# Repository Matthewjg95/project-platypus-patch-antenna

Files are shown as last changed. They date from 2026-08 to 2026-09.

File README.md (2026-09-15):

# Project Platypus — 2.4 GHz Microstrip Patch Antenna

A directional 2.4 GHz patch antenna on 2-layer FR4, designed from first principles —
no antenna generator, no reference design, no copied footprint. Every dimension is
derived from the cavity model and Hammerstad–Jensen microstrip synthesis, then
validated on manufactured hardware over a real RF link.

**Status: manufactured and functional. Gain vs the host's internal antenna is not
yet characterised.**

An early measurement produced an anomalously high delta and was excluded from
conclusions pending repeatability. Characterisation is in progress under a
controlled procedure — see [`TEST_PROCEDURE.md`](TEST_PROCEDURE.md) and
[`VNA_TEST_PLAN.md`](VNA_TEST_PLAN.md).

**Commercialization milestone:** On September 4, 2026, the Rev 2 development
project was **approved** for the Tindie × NextPCB Hardware Creator R&D Support
Program after applying on August 30. The award provides three monthly rounds of
standalone PCB-prototyping and international-shipping support. Rev 2 remains an
engineering-validation build: a sales listing is still gated on design review,
DFM, repeatable RF testing, and pilot-readiness evidence. Later support rounds
may be redirected to Platypus One carrier-board fabrication if the antenna
converges without another justified spin. See [`MILESTONES.md`](MILESTONES.md).

> Board photos: the panel is purple ENIG and photographs beautifully — see the Hackster
> project this repo accompanies.

---

## The board

One 58 × 210 mm V-scored panel, three antennas. Each board is 58 × 70 mm with an
M3 mounting pattern (44 mm square, matching the M5Tab5), a 50 Ω microstrip feed, and an
edge-launch MMCX jack (Cinch/Johnson 135-3711-801) seated in a routed notch.

### Why three designs on one panel

Impedance matching a patch has two textbook solutions. Rather than pick one on faith,
the panel carries **all three variants side by side** — same substrate, same fab run,
directly comparable:

| Design | Matching method | Geometry | Predicted Rin |
|---|---|---|---|
| **A** | Inset feed, calculated match | y₀ = 9.81 mm, slot 6.3 mm | 50 Ω (matched) |
| **B** | Inset feed, deliberate mismatch | y₀ = 7.50 mm, slot 6.3 mm | 97 Ω (control) |
| **C** | Quarter-wave transformer | Z_t = 100 Ω, w = 0.709 mm, ℓ = 17.98 mm | 50 Ω via λ/4 |

Design B is intentionally mismatched — the control that tests whether the matching
model is doing what the math claims.

---

## Design math (all first-principles)

Substrate: FR4, h = 1.6 mm, εr = 4.4, tan δ ≈ 0.02, 2 layers, ENIG.

```
Patch width      W = c/(2f₀)·√(2/(εr+1))                    = 38.04 mm
Effective εr     εr_eff = (εr+1)/2 + (εr−1)/2·(1+12h/W)^−½   = 4.086
Fringing ext.    ΔL = 0.412h·((εr_eff+0.3)(W/h+0.264)) /
                          ((εr_eff−0.258)(W/h+0.8))         = 0.742 mm
Patch length     L = c/(2f₀√εr_eff) − 2ΔL                    = 29.44 mm
50 Ω feed width  (Hammerstad–Jensen, FR4 1.6 mm)             = 3.1 mm
Inset depth      Rin(y₀) = Rin_edge·cos²(πy₀/L) → 50 Ω       = 9.81 mm
λ/4 transformer  Z_t = √(50·200) = 100 Ω, w = 0.709 mm, ℓ    = 17.98 mm
```

Resonance check: L_eff = 29.44 + 2(0.742) = 30.924 mm, √εr_eff = 2.021
→ **f₀ = 2.3996 GHz**.

**Inset slot width follows the Salmony method:** clearance each side of the feed must be
≥ the substrate height h, giving a 6.3 mm total slot (3.1 + 2×1.6). A slot barely wider
than the feed is a common mistake that creates spurious resonances and spoils the match.

### Honest analysis notes

- **Return loss is not signal loss.** A mismatch costs only 10·log₁₀(1−|Γ|²): even
  Design B's deliberate 97 Ω feed point loses well under 2 dB of delivered power. The
  A/B/C comparison therefore needs an S11 sweep (VNA), not RSSI — whatever advantage a
  patch shows over a chip antenna comes from directivity and escaping the host
  enclosure, not from matching finesse.
- **Front-to-back is modest by design.** The ground plane extends only 10–12 mm
  (≈0.1 λ) past the patch, so realistic F/B is ~6–10 dB. Fine for "point the gain at
  the far node"; don't expect a deep rear null indoors.

---

## Manufacturing notes (learned on real hardware)

- **ENIG is required** — HASL's uneven surface degrades RF pads.
- JLCPCB parses V-score geometry from **Edge.Cuts/GM1 only** — order notes and
  Dwgs.User lines are ignored. Their V-cut minimum panel size is 70 × 70 mm.
- The Edge.Cuts outline must be closed loops with exactly two segments per vertex; the
  MMCX notches are separate internal rectangles sharing no vertices with the perimeter.
- The MMCX signal pad sits inside the routed notch — contact is made by the connector's
  spring pin, and the corresponding DRC "unconnected" items are by design (waived in
  `patch_antenna_smp.kicad_dru` / DRC exclusions).
- Solder mask over the radiator shifts resonance down slightly (~10–30 MHz) but does
  not prevent operation.

## Repository layout

This repo now carries the **full project**, not just the manufactured revision — see
[`PROJECT_STATUS.md`](PROJECT_STATUS.md) for the live status, revision map, and
open decisions.

```
patch_antenna_smp.kicad_pcb      Rev 7.13.1 — the MANUFACTURED revision (do not edit)
gerbers/  +  gerbers.zip         Rev 7.13.1 fab package as manufactured (JLCPCB)
DRC7.13.1.rpt                    DRC report of the manufactured revision
patch_antenna_smp_rev8.*         Rev 8 — 3×3 panel respin (lessons-learned; superseded)
patch_antenna_smp_rev9.*         Rev 9 — dual SMT connector lands (u.FL + MMCX); current
rev9_fab/ + rev9_gerbers_jlcpcb.zip   Rev 9 JLCPCB fab+assembly package (BOM/CPL included)
rev8_backups/, rev9_backups/     Staged design snapshots (rollback points)
REV8_PLAN.md, REV9_CONNECTORS.md Revision change logs & design decisions
DESIGN_915_MESHTASTIC.md         915 MHz Meshtastic/LoRa patch — design study
DESIGN_NOTES_v72.md              Full first-principles derivation, BOM, fab notes
TEST_PROCEDURE.md                Over-the-air RF test protocol
VNA_TEST_PLAN.md                 Bench characterisation milestones (S11, gain, pattern)
PROJECT_STATUS.md                Current state, toolchain notes, transfer guide
BOM/Links.txt                    Component sourcing
```

## Bill of materials (per board)

| Ref | Part | Notes |
|---|---|---|
| J1 | MMCX 135-3711-801 (Cinch/Johnson) | Edge-launch jack, board notch |
| H1–H4 | M3 × 6 mm screw + 5 mm nylon standoff | Nylon preferred for RF isolation |
| — | Pigtail: SMP-male → MMCX-male, RG178, ~100 mm | Host-device dependent |

**Fab settings:** 2-layer FR4 1.6 mm, ENIG, purple mask, white silk,
V-score at 70 mm and 140 mm from panel top.

## License

Hardware and documentation are released under the
**[CERN Open Hardware Licence v2 — Strongly Reciprocal](LICENSE)** (CERN-OHL-S v2).
You may use, study, modify, manufacture and sell this design, provided derivative
hardware designs are shared under the same terms.

---

*Project Platypus — Open Source RF*

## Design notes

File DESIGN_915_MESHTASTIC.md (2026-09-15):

# Project Platypus — 915 MHz Meshtastic/LoRa Patch (design study)

*Started 2026-07-05. First-principles design, same method as the proven 2.4 GHz panel.*

## Target

Directional gain antenna for Meshtastic / LoRa point-to-point links, US 902–928 MHz band.
Design frequency: **906.875 MHz** (Meshtastic US LongFast default primary), not 915 —
the patch is narrowband, so tune to where the traffic actually is. An EU868 variant
(869.525 MHz) is a later length-scale respin.

## First-principles dimensions (FR4, h = 1.6 mm, εr = 4.4, tan δ = 0.02)

```
f0 = 906.875 MHz            λ0 = 330.7 mm
Patch width W    = 100.66 mm
εr_eff           = 4.258
ΔL (fringing)    = 0.745 mm
Patch length L   = 78.67 mm
50 Ω feed width  = 3.06 mm   (Hammerstad-Jensen; same as 2.4 GHz design)
100 Ω xfmr width = 0.709 mm ; λg/4 = 47.6 mm  (transformer variant — long, see below)
Inset (200 Ω edge assumption):  y0 = 26.22 mm
Inset (Balanis edge ~376 Ω):    y0 = 29.99 mm
Bandwidth (VSWR<2): ~0.41 % ≈ 3.7 MHz
```

**Feed choice: inset feed.** The λ/4 transformer costs 47.6 mm of board height at this
frequency; the inset is free. (The 2.4 GHz A-vs-C test showed matching method makes <1 dB
difference — pick the compact one.)

## THE design risk at 915: FR4 εr tolerance vs. 3.7 MHz bandwidth

f0 sensitivity at fixed geometry (designed for εr = 4.4):

| FR4 εr actual | f0 lands at | shift |
|---|---|---|
| 4.2 | 927.9 MHz | +21 MHz |
| 4.4 | 906.9 MHz | 0 |
| 4.6 | 887.2 MHz | −20 MHz |

A ±0.2 εr batch spread moves resonance **±20 MHz against a 3.7 MHz bandwidth** — a 5×
overshoot. At 2.4 GHz we got away with this (BW ~25 MHz, same fractional shift); at 915
we will not. Mitigation, in the proven Project Platypus style — **bracket panel**:

| Variant | L | f0 if εr=4.4 | covers εr ≈ |
|---|---|---|---|
| A (short) | 77.09 mm (−2%) | 925.0 MHz | ~4.2 |
| B (nominal) | 78.67 mm | 906.9 MHz | ~4.4 |
| C (long) | 80.24 mm (+2%) | 889.4 MHz | ~4.6 |

One panel run tells us the batch's real εr; the winning variant becomes the product
geometry for that fab. Selection can be done with Meshtastic's own RSSI/SNR reports
between two nodes; a NanoVNA (on the roadmap) makes it a 5-minute S11 sweep instead.

## Board / panel

- Patch 100.7 × 78.7 mm → board ~**130 × 115 mm** (12–15 mm ground margin + feed run).
  Margins are only ~0.04 λ — front-to-back will be modest (~6–10 dB), same physics as
  the 2.4 GHz board. Fine for "point the gain at the far node"; don't market F/B.
- 3 variants stack into a 1×3 V-scored panel ~130 × 345 mm, or 2×3 (~260 × 345) for
  bracket + spare. Both exceed JLCPCB's 70 mm V-cut minimum in both axes. V-cuts on
  Edge.Cuts (GM1), keep-all-islands ground — all per the Rev 8 playbook.
- Solder mask: **openings over the patch** (bare ENIG radiator) — carry the Rev 8 fix.
  At 0.4 % bandwidth we cannot afford unmodelled mask detune.
- Mounting: keep the M3 hole pattern idea, sized for a mast clamp / zip ties instead of
  the M5Tab5 pattern.

## Connector (product-driven, differs from the Tab5 board)

- **On-board: u.FL/IPEX jack** (vertical SMT, ~$0.40). It is the de facto standard on
  Heltec/RAK/LILYGO Meshtastic nodes, needs no routed notch, no edge-launch DRC waivers,
  no spring-pin ambiguity — the feed simply ends in a pad, grounds via to the plane.
- **Ship with a u.FL → SMA-male pigtail** so it also screws straight onto boxed nodes
  (SMA female bulkhead), covering both halves of the market with one SKU.
- Optional second footprint position for a vertical SMT MMCX jack (e.g. Cinch
  135-3701-201) sharing the feed end — populate either. Decide after the 2.4 GHz
  connector experiments.

## Roadmap / open items

1. Freeze bracket-panel geometry; build the KiCad board (new project dir, not in the
   2.4 GHz tree).
2. **NanoVNA** purchase → measure S11 of 2.4 GHz Rev 7.13 A/B/C first (validates the
   whole design chain and the 200 Ω edge-resistance assumption), then use for 915
   variant selection.
3. EU868 respin (scale L for 869.525 MHz) once US geometry is proven.
4. Field range test: two Meshtastic nodes, omni-vs-patch A/B, logged SNR vs distance —
   that's also the marketing material.

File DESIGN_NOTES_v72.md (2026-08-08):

# Project Platypus — 2.4 GHz Patch Antenna
## Design Notes Rev 7.2 — Release for Manufacture

---

## Project Overview

A panelised 2.4 GHz microstrip patch antenna PCB designed for external antenna integration with the M5Tab5. Three distinct impedance-matching designs are included on a single V-scored panel for comparative RF testing. The winning design will be used in Rev 8 production boards. Performance is quantified using the M5Tab5's own WiFi RSSI and the BMI270 gyroscope to render a live 3D radiation pattern on the display.

---

## Board Summary

| Parameter | Value |
|---|---|
| Target frequency | 2.4 GHz (802.11b/g/n, Bluetooth, Zigbee) |
| Panel size | 58 × 210 mm (3 boards × 70 mm each) |
| Individual board | 58 × 70 mm |
| Substrate | FR4, h = 1.6 mm, εr = 4.4, tan δ = 0.02 |
| Copper layers | 2 (F.Cu patch + feed, B.Cu full ground plane) |
| Surface finish | ENIG |
| Solder mask | **Purple** |
| Silkscreen | **White** (both sides) |
| Panelisation | V-score between boards (2 score lines) |
| Mounting | M3 NPTPH, 44 mm square pattern (matches M5Tab5) |
| Connector | MMCX 135-3711-801 end-launch jack, board notch |

---

## Patch Antenna Calculations

All dimensions derived from first principles for 2.4 GHz on FR4 1.6 mm.

### Patch Width

```
W = c / (2f₀) × √(2 / (εr + 1))
W = 3×10⁸ / (2 × 2.4×10⁹) × √(2 / 5.4)
W = 38.04 mm
```

### Effective Dielectric Constant

```
εr_eff = (εr+1)/2 + (εr-1)/2 × (1 + 12h/W)^(-0.5)
εr_eff = 4.086
```

### Patch Length

```
ΔL = 0.412h × (εr_eff+0.3)(W/h+0.264) / ((εr_eff-0.258)(W/h+0.8))
ΔL = 0.742 mm

L_eff = c / (2f₀√εr_eff) = 30.93 mm
L = L_eff - 2ΔL = 29.44 mm
```

### 50 Ω Microstrip Feedline

```
Feed width W_feed = 3.1 mm  (Hammerstad-Jensen, FR4 1.6 mm)
εr_eff_feed ≈ 3.38
```

### Inset Slot Width (Salmony method)

Slot clearance on each side of the feedline must be ≥ substrate height h to prevent capacitive coupling into the patch copper:

```
Slot clearance = h = 1.6 mm each side
Total slot width = W_feed + 2h = 3.1 + 3.2 = 6.3 mm
```

This corrects the common mistake of using a slot barely wider than the feedline, which creates spurious resonances and degrades the impedance match.

---

## Three Designs

### Design A — Inset Feed, Calculated Match (Reference)

The inset feed exploits the cosine-squared current distribution of the patch. Input impedance varies from ~200 Ω at the radiating edge to 0 Ω at the patch centre. The inset depth y₀ selects the exact point where impedance equals 50 Ω.

```
Rin(y₀) = Rin_edge × cos²(π y₀ / L)
50 = 200 × cos²(π y₀ / 29.44)
y₀ = 9.81 mm
Rin at y₀ = 50.0 Ω  ✓ matched
Slot: 6.3 mm wide × 9.81 mm deep
```

**This is the primary design.** Expected best broadside gain.

### Design B — Inset Feed, Deliberate Mismatch (Experiment)

Identical geometry to Design A but with a shallower inset. The feed point is higher up the patch where impedance is ~97 Ω rather than 50 Ω. This controlled mismatch tests the sensitivity of the antenna to inset depth error and provides data to validate the matching formula experimentally.

```
y₀ = 7.50 mm  (shallower than calculated optimum)
Rin at y₀ = 97.0 Ω  → mismatch Γ = (97-50)/(97+50) = 0.32
Expected return loss ≈ 9.8 dB  (vs >20 dB for Design A)
```

**Expected measurably worse RSSI than Design A.** If the delta is not observed, it suggests the 50 Ω assumption for the feedline is the dominant error, not the inset depth.

### Design C — Quarter-Wave Transformer (Alternative Matching)

No inset notch. The 50 Ω feedline transitions to a higher-impedance transformer section before connecting to the centre of the patch's radiating bottom edge. The transformer impedance Z_t and length λ_g/4 perform the same 200 Ω → 50 Ω transformation as the inset, but via an external line section rather than feed positioning.

```
Z_t = √(Z₀ × Rin) = √(50 × 200) = 100 Ω
Transformer width W_t = 0.709 mm  (100 Ω microstrip, FR4 1.6 mm)
εr_eff_t = 3.118
λ_g/4 at 2.4 GHz = c / (4 × f₀ × √εr_eff_t) = 17.98 mm
```

The patch is a plain rectangle with no notch slots. The feed enters at the bottom-centre radiating edge. The step from 3.1 mm (50 Ω) to 0.709 mm (100 Ω) is an abrupt width change — the standard Salmony method. Bandwidth of this match is similar to the inset approach.

**Useful for comparison:** if Design C outperforms Design A it suggests the inset slots are introducing parasitic coupling despite the 1.6 mm clearance.

---

## Connector — MMCX 135-3711-801

End-launch jack receptacle, surface mount, Bel/Cinch group. Selected for compatibility with the M5Tab5's MMCX external antenna ports.

| Pad | Net | Size | Position (rel. to footprint origin) |
|-----|-----|---|---|
| 1 (signal) | RF_IN | Ø 0.71 mm | (0, +3.30 mm) — inside notch |
| 2 (GND left) | GND | 0.97 × 1.47 mm | (−2.235, −0.735 mm) |
| 3 (GND right) | GND | 0.97 × 1.47 mm | (+2.235, −0.735 mm) |

**Board notch:** 3.50 mm wide × 4.50 mm deep, rectangular, routed into the board bottom edge. The signal pad sits 3.30 mm below the board edge inside the routed slot. The feedline copper terminates exactly at the board edge — it does not extend into the notch.

**Pigtail cable:** SMP male to MMCX male, RG178, ~100 mm. Plugs into M5Tab5 MMCX port and snaps into J1 on this PCB.

---

## Panel & Fabrication

### V-Score Panelisation

The three boards share a single continuous `Edge.Cuts` outline (one panel). V-score lines run the full panel width at y = 113.5 mm and y = 183.5 mm in panel coordinates (= 70 mm and 140 mm from the panel top edge). JLCPCB will route the MMCX notch slots first, then apply the V-score blade.

**JLCPCB order note to include:**
> "V-score at 70 mm and 140 mm from panel top edge (panel y = 113.5 mm and y = 183.5 mm). Three MMCX slots (3.50 × 4.50 mm) pre-routed at each board bottom edge. No solder mask on F.Cu patch copper areas. Purple solder mask, white silkscreen, ENIG finish."

### Critical Fabrication Requirements

- **No solder mask on patch copper** — solder mask over the radiating element changes εr_eff and shifts the resonant frequency. Specify a solder mask opening over the patch polygon on each board (the Gerbers include this as a B.Mask opening).
- **ENIG finish** — required for RF performance. HASL creates uneven surface topology under the connector pads and patch copper.
- **Purple solder mask** — select in JLCPCB order form. No extra cost for 2-layer boards. Turnaround +2 days vs green.
- **White silkscreen** — default for purple mask, no action needed.

### Mounting

M3 NPTPH holes (3.2 mm drill, no plating) in a 44 mm square pattern, 7 mm from each board side, 5 mm from board top. This matches the M5Tab5's M3 mounting point positions exactly. Use M3 socket-head cap screws with nylon spacers to mount the antenna PCB above the M5Tab5 body with the patch face pointing away from the device.

---

## Bill of Materials

| Ref | Part | Qty (per board) | Notes |
|-----|---|---|---|
| J1 | MMCX 135-3711-801 (Bel/Cinch) | 1 | DigiKey, Mouser |
| H1–H4 | M3 × 6 mm socket head cap screw | 4 | Nylon preferred for RF isolation |
| H1–H4 | M3 nylon standoff, 5 mm | 4 | Between this PCB and M5Tab5 |
| — | SMP male to MMCX male pigtail, RG178, 100 mm | 1 | Pasternack, Amazon |
| PCB | This file, JLCPCB 2-layer | 1 panel (3 boards) | Purple, ENIG |

**Note:** Order 2 panels (10 boards) for testing redundancy. At JLCPCB pricing this is approximately $8–12 shipped.

---

## Key Design Decisions & Revision History

| Rev | Change |
|-----|---|
| 1.0 | Initial inset-feed patch, SMP edge connector |
| 2.0 | Updated to MMCX 135-3711-801, M3 holes, 44 mm pattern |
| 3.0 | Three-design panel (A/B/C), V-score panelisation |
| 4.0 | Patch moved inside mounting hole square, board notch corrected to rectangular |
| 5.0 | Single panel Edge.Cuts outline (boards actually connected), patch U-polygon with visible notch slots |
| 5.1 | Feed copper capped at board edge (was extending 3.3 mm past edge into routed notch — fabrication error) |
| 6.0 | Panel properly connected, V-score lines on Dwgs.User |
| 7.0 | Slot width corrected from 4.1 mm to 6.3 mm per Salmony method (h clearance each side). Purple solder mask specified. Project Platypus branding. |
| 7.1 | Logo moved to B.SilkS back silkscreen, notes box placed outside board boundary |
| 7.2 | Logo replaced with "Project Platypus" text in lower-right corner. Notes box corrected. |
| 7.3–7.13 | DRC iteration: zone priorities fixed, GND zone unified, vias removed (no F.Cu GND to stitch to), connector GND zones with vias added, MMCX edge clearances waived, Edge.Cuts rebuilt as outer perimeter + 2 internal notch rectangles (no T-junctions), V-score positions verified at y=113.5 and y=183.5. **Release for manufacture.** |

---

## Expected Performance

| Metric | Design A | Design B | Design C |
|---|---|---|---|
| Resonant frequency | 2.40 GHz | 2.40 GHz | 2.40 GHz |
| Return loss (S11) | > 20 dB | ~10 dB | > 15 dB |
| Bandwidth (−10 dB) | ~80 MHz | ~30 MHz | ~70 MHz |
| Gain (broadside) | 5–7 dBi | 3–5 dBi | 4–6 dBi |
| RSSI delta vs stock | +4 to +7 dBm | +1 to +3 dBm | +3 to +5 dBm |

All values are estimates based on standard FR4 patch theory. Actual performance will be measured per the TEST_PROCEDURE.md protocol.

---

## Next Steps After Receipt

1. **Visual inspection** — confirm purple mask, white silk, ENIG finish, MMCX notch clean
2. **VNA measurement** — if available, measure S11 on each board before RF testing. Resonance within ±50 MHz of 2.4 GHz is acceptable without rework
3. **Connector installation** — solder J1 (MMCX 135-3711-801) with paste and reflow or careful iron work. Pads are small — use flux
4. **RF switch** — confirm M5Tab5 GPIO for antenna switching (external vs chip antenna). Check Tab5 schematic for GPIO number controlling the RF switch on the ESP32-C6-MINI-1U
5. **Follow TEST_PROCEDURE.md** — baseline first, then each design in order A → B → C
6. **3D pattern capture** — run the full hemisphere sweep on the winning design, process with the Python pipeline, render on M5Tab5 display via Three.js + BMI270 gyro

---

*Project Platypus — Open Source RF*
*Rev 7.2 — Ready to manufacture*

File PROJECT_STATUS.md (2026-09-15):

# Project Platypus — Status & Transfer Guide

*Last updated 2026-09-14. This file exists so the whole project moves between machines
with one `git clone` and no tribal knowledge. Everything below is in this repo.*

## What this project is

First-principles 2.4 GHz microstrip patch antennas (KiCad, FR4 1.6 mm), plus a product
track (Tindie) and a 915 MHz Meshtastic design study. Full derivations in
`DESIGN_NOTES_v72.md` and the README.

**Measurement status:** the boards are manufactured and functional. An early RSSI
delta vs the host chip antenna was anomalously high and has been withdrawn pending a
controlled re-test — do not cite it. Bench characterisation plan: `VNA_TEST_PLAN.md`.

## Revision map

| Revision | File(s) | State |
|---|---|---|
| **Rev 7.13.1** | `patch_antenna_smp.kicad_pcb` (+`.kicad_pro`, `.kicad_dru`), `gerbers/`, `gerbers.zip`, `DRC7.13.1.rpt` | **Manufactured.** 1×3 panel, edge-launch MMCX. Never edit in place. |
| **Rev 8** | `patch_antenna_smp_rev8.*`, `REV8_PLAN.md`, snapshots in `rev8_backups/` | Complete + DRC-verified. 3×3 panel 174×210 mm, V-cuts on Edge.Cuts, keep-all-islands ground, bigger MMCX pads, mask experiment (left column bare / two masked). Superseded by Rev 9 for ordering. |
| **Rev 9** | `patch_antenna_smp_rev9.*`, `REV9_CONNECTORS.md`, snapshots in `rev9_backups/`, fab package `rev9_fab/` + `rev9_gerbers_jlcpcb.zip` | Complete + DRC-verified. Dual SMT lands per board: Hirose U.FL (JUA–JUI) + Würth vertical MMCX (JMA–JMI), no notches. **This is the revision to order.** |
| **915 MHz** | `DESIGN_915_MESHTASTIC.md` | Design study done, KiCad board not started. Key: 3-length bracket panel (FR4 εr tolerance vs 3.7 MHz bandwidth). |

## Pending / open decisions

1. **Rev 9 fabrication order** — package is upload-ready. Funding (see
   `MILESTONES.md`): the Tindie × NextPCB vouchers ($30/mo ×3 + shipping) cover
   **standalone PCB fabrication at NextPCB only — not PCBA**; the separate $20
   JLCPCB credit can offset a JLCPCB assembly order. Options: (a) NextPCB
   bare-panel run on the voucher + hand-solder connectors, or (b) JLCPCB PCBA —
   u.FL from their library (Hirose **C88373**), Würth MMCX via Global Sourcing
   (~$4–5/pc, +1 wk) or hand-soldered. Population map in `rev9_fab/BOM_rev9.csv`
   / `CPL_rev9.csv` (MMCX cols 1&3, u.FL col 2). If using JLC assembly, check
   connector rotations in their preview (u.FLs are at −90°). Per MILESTONES.md,
   any new spin beyond this must be justified by measurement, not coupon availability.
2. **VNA milestones** (`VNA_TEST_PLAN.md`): buy a NanoVNA-V2 Plus4 / LiteVNA-64 (NOT
   the original NanoVNA); M1–M2 on the Rev 7.13 boards settle the patch-A connector
   question and the Rin_edge assumption. M5 (gain/pattern) uses the work radar bench —
   this produces the number that replaces the withdrawn claim.
3. **915 bracket panel**: start KiCad board after the Rev 9 order is in flight.

## Toolchain & workflow (as used to build Rev 8/9)

- **KiCad 10.0.1.** GUI plus headless: `kicad-cli` and the bundled Python
  (`C:\Program Files\KiCad\10.0\bin\python.exe`, module `pcbnew`) for scripted edits.
- **Validation is a DRC delta-check**: `kicad-cli pcb drc` does NOT apply GUI
  exclusions, so compare violation *categories* against the documented expected set
  (see `REV9_CONNECTORS.md` § verified DRC state), not against zero. It DOES honor
  `.kicad_dru` custom rules.
- Always **Fill All Zones (B) in the GUI before export** after any zone edit.
- pcbnew scripting gotchas (hard-won): `LoadBoard` twice in one process returns a raw
  SwigPyObject — run phases as separate processes; removing tracks in a loop can
  segfault — prefer add-only edits; `Duplicate()` needs `.Cast()` and loses nothing
  but check nets anyway.
- Windows: ignore SWIG "memory leak" stderr noise from pcbnew scripts.

## Moving to a new machine

```
git clone https://github.com/Matthewjg95/project-platypus-patch-antenna.git
```

Then: install KiCad ≥10, `gh auth login`, set git identity, and open
`patch_antenna_smp_rev9.kicad_pcb`. The `rev8_backups/`/`rev9_backups/` folders are
staged design snapshots (rollback points); git history is authoritative. Not in the
repo (by design): `.history/` editor cache, `*.kicad_prl` window state, vendor
datasheet PDFs (links in `BOM/Links.txt`).

## Product / licensing

CERN-OHL-S v2 (`LICENSE`). Commercial sale is permitted by the license, and as sole
copyright holder you may also dual-license. Tindie plan: bare / assembled / kit SKUs;
market via Meshtastic + ELRS communities once characterisation data exists.

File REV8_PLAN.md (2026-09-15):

# Project Platypus — Rev 8 Plan

## Status
Rev 7.13.1 is manufactured, assembled, and functional; gain vs the M5Tab5 chip antenna
is not yet characterised. Rev 8 folds in every lesson learned from that build. This file
is the durable change list and the record of design decisions made while implementing it.

The known-good manufactured file (`patch_antenna_smp.kicad_pcb`, the 1×3 panel) is **not**
edited in place. Rev 8 work happens on a copy so the shipped design is always recoverable.

---

## Implementation status — 2026-07-05

Rev 8 is built on the working copy `patch_antenna_smp_rev8.kicad_pcb` (staged snapshots in
`rev8_backups/`). Validated with `kicad-cli 10.0.1` (delta check — it does not apply the
GUI `.kicad_dru` waivers or exclusions, so by-design items always appear).

**Done and verified:**
- MMCX GND pads enlarged to 1.5×2.0 mm; feed tapered 3.1→1.0 mm; 2.0×2.0 signal-pad mask
  aperture + patch F.Mask openings. DRC delta clean (no new categories) on the 1×3.
  (snapshots `rev8_02`)
- 3×3 panel 174.1×210.1 mm: 9 boards (JA–JI + 36 M3), 40 zones, 18 vias. Outer perimeter
  + 3 bottom C-notches + 6 internal A/B notches rebuilt clean. GND_PANEL extended to full
  panel and set to **keep-all islands** so every board keeps its own ground (inset 0.5 mm
  from score lines) — fill 34,909 mm² across all 9 boards. V-cut lines added on Edge.Cuts
  between all rows (y=113.5, 183.5) and columns (x=239, 297). (snapshots `rev8_04`, `rev8_05`)
- Broadened `.kicad_dru` edge-clearance waiver to all F.Cu GND pads (covers JA–JI).
- Title/rev strings updated to Rev 8.

**Final panel DRC (all expected / waived / by-design — no real defects):**
- `copper_edge_clearance` ×18 — MMCX GND pads on notch walls (waived by `.kicad_dru`).
- `unconnected_items` ×16 — 10 RF_IN (spring-pin contact, by design) + 6 GND (see below).
- `isolated_copper` ×32 — 23 RF_IN patch radiators (by design; reached only via connector
  pin) + 9 GND edge slivers.
- `invalid_outline` ×8 — the four V-cut lines touching the perimeter (the Edge.Cuts V-cut
  tradeoff; exclude).
- `silk_over_copper` ×6 — Design B/C labels (cosmetic; same as Rev 7.13).

**Known non-issue — 6 GND `unconnected_items`:** the left-side connector grounds in columns
1–2 (`CONN_GND_*_L_C1/C2`) show a ratsnest line to GND_PANEL. Proven a headless-fill
connectivity artifact: each via is geometrically inside both its F.Cu CONN_GND fill and the
B.Cu ground plane, on the same net (netcode 2), identical to the working column-0 / right-side
connections. It is functionally harmless regardless — the MMCX body shorts pads 2 & 3, and the
right-side via grounds every connector. Should resolve on GUI Fill All Zones. Do NOT "fix" by
adding in-pad vias near the notch (they violate edge clearance).

**Open decision — V-cuts on Edge.Cuts vs. continuous ground:** current design puts V-cuts on
Edge.Cuts (per the JLCPCB lesson that Dwgs.User is ignored). Cost: 8 `invalid_outline`
warnings + the ground fragmenting into per-board tiles (handled with keep-all). Alternative:
keep V-cuts off Edge.Cuts for a continuous plane + clean DRC, and communicate V-cut positions
to JLCPCB another way. Left as-is pending user preference.

## RF design parameters (locked — unchanged from Rev 7)
```
Frequency        2.4 GHz            Patch width W     38.04 mm
Substrate        FR4 1.6 mm         Patch length L    29.44 mm
εr 4.4, tanδ 0.02  εr_eff 4.086     ΔL (fringing)     0.742 mm
50 Ω feed width  3.1 mm             Rin at edge       ~200 Ω
Design A inset   y0 = 9.81 mm → 50 Ω (matched)
Design B inset   y0 = 7.50 mm → 97 Ω (deliberate mismatch)
Design C xfmr    Zt = 100 Ω, w = 0.709 mm, L = 17.98 mm (no inset)
```
No RF geometry changes in Rev 8 — the electrical design is validated. Rev 8 is purely
manufacturability + panelisation improvements.

---

## Change list

### 1. MMCX 135-3711-801 footprint — manufacturability fixes
Problems seen on Rev 7.13:
- **Feed crowding.** 3.1 mm feed in a 3.50 mm notch = 0.2 mm clearance per side; the
  connector GND legs nearly shorted to the signal feed. (Rev 7.13 workaround: solder
  mask over the feed insulated the legs.)
- **No usable mask opening on the signal pad.** Had to scrape mask by hand before
  soldering. (The pad *had* F.Mask in its layer list, but the 0.71 mm opening was too
  small/tight to be useful.)
- **GND pads too small** for Class 3 workmanship (0.97 × 1.47 mm).

Rev 8 fixes (geometry decided during implementation — see "Decisions" below):
- ~~Taper the feed from 3.1 mm to 1.0 mm.~~ **REVERTED 2026-07-05.** The routed connector
  notch (the "hole") already separates the feed from the GND legs — the feed fill is clipped
  at the notch edge and the spring pin bridges to the signal pad, so there is no real feed-to-
  GND crowding. Tapering just removed copper and added a needless impedance discontinuity.
  Feed is back to straight 3.1 mm microstrip (the proven Rev 7.13 geometry).
- **Signal-pad mask aperture 2.0 × 2.0 mm**, added as a mask-only pad centred on the
  signal pad, so the whole pin-contact area is bare ENIG.
- **GND pads enlarged to 1.5 × 2.0 mm.** Grown *outward in x* (inner edge kept exactly
  on the notch wall) and *upward in y* (bottom edge kept flush with the board edge).
  The connector's ground leg still lands well inside the enlarged pad.

### 2. Solder mask off the radiator — bare-vs-masked A/B test
Rev 7.13 shipped with **no** F.Mask openings over the patch copper (mask covered the
patches). It worked but detuned resonance ~10–30 MHz downward. Rev 8 makes patch masking a
deliberate experimental variable: **the LEFT column (all 3 designs A/B/C) is bare copper**
(F.Mask opening over the patch), and the **middle + right columns are masked**. That gives a
bare-vs-masked pair for every design so the mask detuning can be measured per design without
confounding it with the design difference. The bare patches read gold/ENIG, the masked ones
purple — self-identifying, no silk label needed (a note is added to the User.Drawings legend).
The **feed stays masked** everywhere on purpose — mask over a transmission line is negligible
and it insulates the connector GND legs from the feed. Only the left-column radiators go bare.
(Earlier interim state had all 9 patches bare; narrowed to one column on user request.)

### 3. Panelisation — 3×3, V-cuts on Edge.Cuts
Rev 7.13 was a 58 × 210 mm 1×3 panel. Two problems at JLCPCB:
- **Below V-cut minimum.** JLCPCB's V-cut minimum panel size is 70 × 70 mm; our 58 mm
  width was under it, so they could not V-score horizontally between designs.
- **V-scores on Dwgs.User were ignored.** JLCPCB parses geometry on Edge.Cuts / GM1,
  not Dwgs.User. Order notes are not a substitute.
- JLCPCB "helpfully" multiplied our panel into a 3×3 array (174 × 210 mm) anyway.

Rev 8 plan: design the full **3×3 panel = 174 × 210 mm** up front (both dimensions
> 70 mm), 3 columns × 3 rows = 9 boards, one design per row (A / B / C), three copies of
each across the columns. V-cut lines go on **Edge.Cuts** between every row and column.

> **Open technical caveat (V-scores on Edge.Cuts):** a V-score line that spans the full
> panel width and touches the perimeter creates T-junctions, which KiCad reports as
> `invalid_outline`. The clean board shape (outer perimeter + separate internal MMCX
> notch rectangles, no shared vertices) is what keeps DRC quiet. Putting full-span
> V-cut lines back on Edge.Cuts re-introduces those warnings. The resolution is to keep
> the true outline clean and add the V-cut lines as independent Edge.Cuts segments,
> accepting/【excluding】the resulting outline warnings — that is the tradeoff for JLCPCB
> reading them from GM1. This is validated with `kicad-cli pcb drc` during implementation.

### 4. Consider soldermask-defined openings for all connector pads
Evaluate SMD-defined vs mask-defined for the GND and signal pads. Low priority; only if
the enlarged pads still show mask slivers in the fab preview.

---

## Decisions made during implementation

### MMCX footprint geometry (origin = connector centre, at the board edge; +y = toward/past the edge)
| Element | Rev 7.13 | Rev 8 | Rationale |
|---|---|---|---|
| Signal pad (1) | Ø 0.71 @ (0, +3.30) | unchanged copper | pin contact point is fixed |
| Signal mask | 0.71 (= pad) | **2.0 × 2.0 aperture @ (0, +3.30)** | bare area for hand/reflow solder |
| GND pad L (2) | 0.97 × 1.47 @ (−2.235, −0.735) | **1.5 × 2.0 @ (−2.5, −1.0)** | bigger, inner edge on notch wall, bottom flush to edge |
| GND pad R (3) | 0.97 × 1.47 @ (+2.235, −0.735) | **1.5 × 2.0 @ (+2.5, −1.0)** | mirror of pad 2 |

Notch wall at rel x = ±1.75 (abs 208.25 / 211.75). Enlarged GND pad inner edge = 2.5 −
0.75 = 1.75 → sits exactly on the notch wall (same as Rev 7.13's 2.235 − 0.485 = 1.75),
covered by the existing `edge_clearance (min 0mm)` DRC rule. Bottom edge at rel y = 0 =
board edge (V-score line); grows upward into the board to rel y = −2.0.

### Feed geometry — straight 3.1 mm (taper reverted)
Feed zones are plain 3.1 mm rectangles x [208.45+dx, 211.55+dx] from the patch bottom to the
board edge (dx = 0 / 58 / 116 per column). The fill is clipped by the routed MMCX notch, and
the connector spring pin bridges to the signal pad — no copper crowding, no taper needed.
- Design A feed: y 85.2212 → 113.5
- Design B feed: y 155.2212 → 183.5
- Design C feed: y 243.201 → 253.5 (plus the unchanged XFORM_C 0.709 mm transformer)

### Patch mask openings
Filled polygon on F.Mask over each patch bounding box (radiator only, not feed):
- A: (190.982, 55.779)–(229.018, 85.221)
- B: (190.982, 125.779)–(229.018, 155.221)
- C: (190.982, 195.779)–(229.018, 225.221)

---

## Zone priority hierarchy (unchanged — prevents zones_intersect)
```
PATCH_A/B/C   priority 3   XFORM_C      priority 2
FEED_A/B/C    priority 1   GND_PANEL    priority 0   CONN_GND_*  priority 0
```
- ONE B.Cu GND_PANEL zone covering the whole panel (spans all 3 columns in Rev 8).
- CONN_GND zones: solid fill, `connect_pads yes (clearance 0)`, one via each to GND_PANEL.
- No stitching vias — all F.Cu copper is RF_IN, nothing to stitch.

## Build / verify workflow
1. Edit the Rev 8 copy.
2. **Fill All Zones (press B)** in KiCad — filled_polygon data in the file is stale after
   any zone-outline edit until refilled. `kicad-cli pcb drc` refills before checking.
3. `kicad-cli pcb drc --schematic-parity ... ` — expect only the waived items:
   - `unconnected_items` on RF_IN signal pads (spring-pin contact) — exclude.
   - MMCX GND edge clearance — waived by `.kicad_dru`.
   - Edge.Cuts outline warnings from V-cut lines — exclude (see caveat above).
4. Re-export gerbers to `gerbers/` and re-zip for JLCPCB.

## Fab order (JLCPCB)
Purple mask, white silk, ENIG, FR4 1.6 mm, 2-layer. 3×3 panel 174 × 210 mm. V-cut on
GM1 between all rows and columns. No mask on patch copper. MMCX slots 3.5 × 4.5 mm routed.

## KiCad S-expr pitfalls (carried forward)
- `(justify center)` invalid in older formats — omit (centre is default).
- `fill solid` invalid — use `fill yes`.
- `;;` comments break the parser.
- `gr_rect` cannot carry a net — use `zone` for copper pours.
- Edge.Cuts outline must be closed loops, exactly 2 segments per vertex, no T-junctions.
- Same-net zones touching on the same layer need different priorities.

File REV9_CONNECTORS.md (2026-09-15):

# Rev 9 — Dual SMT Connector Respin (u.FL + vertical MMCX)

*Created 2026-07-21. Working file: `patch_antenna_smp_rev9.kicad_pcb` (branched from Rev 8
snapshot `rev8_08`; Rev 8 remains the frozen fab-ready edge-launch panel). Snapshots in
`rev9_backups/`.*

## Concept

Every board carries **both** connector lands on the feed axis — populate either one:

- **u.FL / IPEX MHF1** (Hirose U.FL-R-SMT-1) — the de facto standard on Meshtastic/LoRa/
  ESP32 dev boards. Vertical mate, cable exits perpendicular to the board face.
- **Vertical SMT MMCX** (Würth WR-MMCX 66012102111404) — locking snap connector, mates the
  existing SMP-to-MMCX pigtail vertically. Fixes the edge-launch "double 90°" cable exit.

Both are placed using the **official KiCad 10 footprints** (datasheet-derived):
`Connector_Coaxial.pretty/U.FL_Hirose_U.FL-R-SMT-1_Vertical` and
`WR-MMCX_Wuerth_66012102111404_Vertical`.

## Default BOM (low-cost)

| Role | Default part | ~Cost (qty 1/100) | Notes |
|---|---|---|---|
| u.FL jack | Hirose U.FL-R-SMT-1(10) | $0.55 / $0.35 | LCSC clones (I-PEX MHF1 compatible, e.g. BWIPX-1-001E) ~$0.10 — same land pattern |
| SMT MMCX jack | Würth 66012102111404 | $3.40 / $2.60 | KiCad-official land. Cheaper LCSC MMCX SMT verticals exist but MUST be pattern-checked against this land before substituting |
| Pigtail (u.FL SKU) | u.FL → SMA-male, RG178, 100–200 mm | $3–5 | covers boxed-node users |
| Pigtail (Tab5 kit) | SMP-male → MMCX-male (existing) | — | mates the vertical MMCX directly |

## Per-board geometry (board coords: cx = column centre, ye = board bottom edge)

```
Feed:        3.1 mm (50 Ω) from patch bottom to ye−9.5
Neck:        0.6 mm wide from ye−9.5 to ye−3.5 (through MMCX wing channel, onto u.FL pad)
MMCX (JM_)   centre at (cx, ye−7), pad1 Ø1.47 on the neck
u.FL (JU_)   centre at (cx, ye−2.5), rotated 270° → signal pad at (cx, ye−4.03) on the neck
             (moved from ye−3.5 after DRC: pad-to-MMCX-wing gap is now 0.34 mm)
GND vias     2 per board inside the MMCX ground wings at (cx−1.71, ye−8.6), (cx+1.67, ye−8.6)
CONN_GND     Rev 8's edge pours + vias retained at (cx±1.75..±5, ye−3.5..ye) — u.FL ground
             pads overlap them directly (same net, solid connect)
```

**DRC accommodations (both required, both in place):**
- The project's `RF_50ohm` netclass (0.5 mm clearance) cannot be met inside the connector
  lands (wing channel 1.07 mm). `patch_antenna_smp_rev9.kicad_dru` adds rule
  `SMT_connector_local_clearance` → 0.2 mm for any pair involving `JU*`/`JM*`. Custom rules
  override netclass, and kicad-cli honors the .kicad_dru (verified empirically).
- `allow_soldermask_bridges_in_footprints = yes` — the Hirose footprint's own mask aperture
  intentionally bridges its pads; this board setting suppresses that false positive.
- FEED/XFORM zones use solid pad connection (thermal spokes starve on a 0.6 mm neck, and
  solid is correct for RF anyway).

## Verified DRC state (kicad-cli, 2026-07-21)

**16 violations, all expected panel artifacts — 0 real defects:**
- `unconnected_items` ×16 — 8× RF_IN feed-zone↔feed-zone across *different boards* (one net
  spanning 9 V-score-separated boards; each board's pad→feed→patch chain IS connected) and
  8× CONN_GND↔GND_PANEL headless-fill bookkeeping (via geometrically verified inside both
  fills; resolves on GUI Fill All Zones).
- `courtyards_overlap` ×9 — the JU/JM pair on each board; never both populated. Waive.
- `invalid_outline` ×7 — V-cut lines on Edge.Cuts, same as Rev 8. Waive.

Gone vs Rev 8: all copper_edge_clearance waivers, spring-pin unconnected pads,
isolated patch copper (patches now DC-connected through the connector pads), silk clipping.

**Why the 0.6 mm neck is required here** (unlike the reverted Rev 8 edge-launch taper): the
Würth MMCX ground wings leave only a 1.07 mm copper channel into the centre pad, and the
u.FL signal pad is 1 mm wide between its own grounds. A 3.1 mm feed physically cannot reach
either pad without shorting to ground. The neck is ~5 mm of ~110 Ω line ≈ 0.07 λg at
2.45 GHz — a small, acceptable discontinuity. **Verify with NanoVNA when it arrives.**

Unpopulated-land stub: whichever connector is not fitted leaves ≤2.5 mm of open 0.6 mm
stub on the feed (≈0.036 λg) — negligible at 2.4 GHz.

## What Rev 9 removed (vs Rev 8)

- 9× edge-launch MMCX 135-3711-801 footprints and their routed notches — **Edge.Cuts is now
  a plain 174×210 rectangle + 4 V-cut lines** (8 segments total). No internal slots at all.
- The 9 stale 2×2 mask apertures and MMCX silk labels; stale feed fab outlines.
- With no notch and no edge-flush pads: the old copper_edge_clearance waivers and
  "signal pad in the notch" unconnected items should disappear from DRC. Ground plane is 9
  clean per-board tiles, 35,008 mm² total (more copper than Rev 8 — no notch cutouts).

## Expected DRC残 items

- Courtyard overlap between JU_/JM_ pairs (never both populated) — waive.
- V-cut invalid_outline ×8 and isolated RF_IN patch copper — same as Rev 8, waive.
- u.FL pad1 connects to the feed neck via zone fill — confirm connection after GUI refill.

## Open items

- [ ] GUI review: fill zones (B), inspect connector cluster at 2× zoom
- [ ] DRC pass in GUI with exclusions
- [ ] Confirm Würth wing-channel clearance (0.235 mm each side of neck) passes the board's
      0.2 mm netclass clearance — if the fab wants more, narrow the neck to 0.5 mm
- [ ] NanoVNA S11 sweep of both connector variants vs the Rev 8 edge-launch baseline
- [ ] Pick the low-cost LCSC MMCX substitute only after overlaying its drawing on this land

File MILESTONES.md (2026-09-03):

# Milestones

## 2026-09-04 — Tindie × NextPCB R&D Support application approved

Application status: **Approved**

The project has been accepted into the Tindie × NextPCB Hardware Creator R&D
Support Program.

### Support awarded

Three monthly support rounds are scheduled for September 5, October 5, and
November 5, 2026. Each round provides:

- **$30 PCB prototyping voucher** for a qualifying standalone PCB manufacturing
  order.
- **$20 international shipping discount code**.
- Each voucher/code is valid for three months from issuance.

Program rules state that the PCB voucher applies to standalone PCB fabrication
orders with no substrate-material or fabrication-spec restriction and no
minimum spend. It does **not** cover PCB cost embedded inside a PCBA order;
assembly and component procurement therefore remain separate project costs.

### Planned allocation

The support is treated as an engineering-iteration budget rather than an
obligation to spin the antenna three times:

1. **September — Rev 2 validation run.** Freeze the audited KiCad package,
   connector implementation, mounting geometry, labeling, and DFM details;
   manufacture the A/B/C comparison panel.
2. **October — evidence-gated Rev 2.1.** Order another antenna revision only if
   controlled RF measurements identify a specific change worth testing.
   Otherwise redirect the fabrication round to a Platypus One carrier/interface
   board.
3. **November — product candidate or Platypus One carrier.** If antenna
   validation closes early, use the final fabrication round to accelerate
   Platypus One hardware development rather than revising a solved antenna.

**Revision rule:** a new antenna spin must be justified by measurement. Coupon
availability alone is not a design-change requirement.

This creates a funded path from Rev 2 through measured validation while
preserving later program capacity for the broader Platypus hardware stack if
the antenna converges early.

### Next gate

Before the September fabrication order:

- complete KiCad source audit;
- run DRC and HQDFM/DFM review;
- verify panel geometry and connector fit;
- confirm Rev 2 fabrication outputs;
- define the exact before/after RF test matrix.

The sales listing remains gated on repeatable RF results, BOM/assembly
instructions, photographs, honest specifications, and pilot-readiness evidence.

---

## 2026-08-30 — Tindie × NextPCB R&D Support application submitted

Application status: **Superseded by approval on 2026-09-04**

Project submitted as:

- **Product:** Project Platypus 2.4 GHz Patch Antenna — Rev 2
- **Tindie status:** Store opened, no eligible orders yet
- **Development stage:** Functional prototype available and ready for optimization
- **Expected 12-month PCB quantity:** 50–200
- **Related product listing:** Not yet published

This was the project's first formal step from a documented open-source RF
prototype toward a small-batch hobbyist product.

### Application development plan

1. Audit the existing KiCad project and released manufacturing files.
2. Define Rev 2 requirements, including connector/cable compatibility,
   labeling, mounting, and manufacturability.
3. Run DRC and DFM review before ordering.
4. Produce 10–20 Rev 2 validation boards.
5. Compare Rev 2 variants against the manufactured revision using the
   repository test procedure and the Project Platypus Antenna Lab workflow.
6. Publish measured, reproducible results without relying on theoretical gain
   claims.
7. Release a 25–50 unit pilot batch on Tindie after the validation gate passes.
8. Reorder in demand-based batches, targeting 50–200 PCBs over 12 months.

### Product-release gate

Approval does **not** mean Rev 2 is production-ready. A public sales listing
waits until all of the following are complete:

- KiCad source and fabrication-output review.
- DRC/DFM acceptance.
- Mechanical and connector-fit verification.
- Repeatable RF comparison against the current boards and host antenna.
- Practical connectivity testing.
- BOM, assembly instructions, photographs, and honest specifications.
- Pilot pricing and fulfillment plan.

Program page:
https://www.tindie.com/campaigns/nextpcb-2026/

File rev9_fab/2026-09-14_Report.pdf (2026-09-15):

## HQDFM Design for Manufacture(DFM) Report

### File name: 2026-09-14

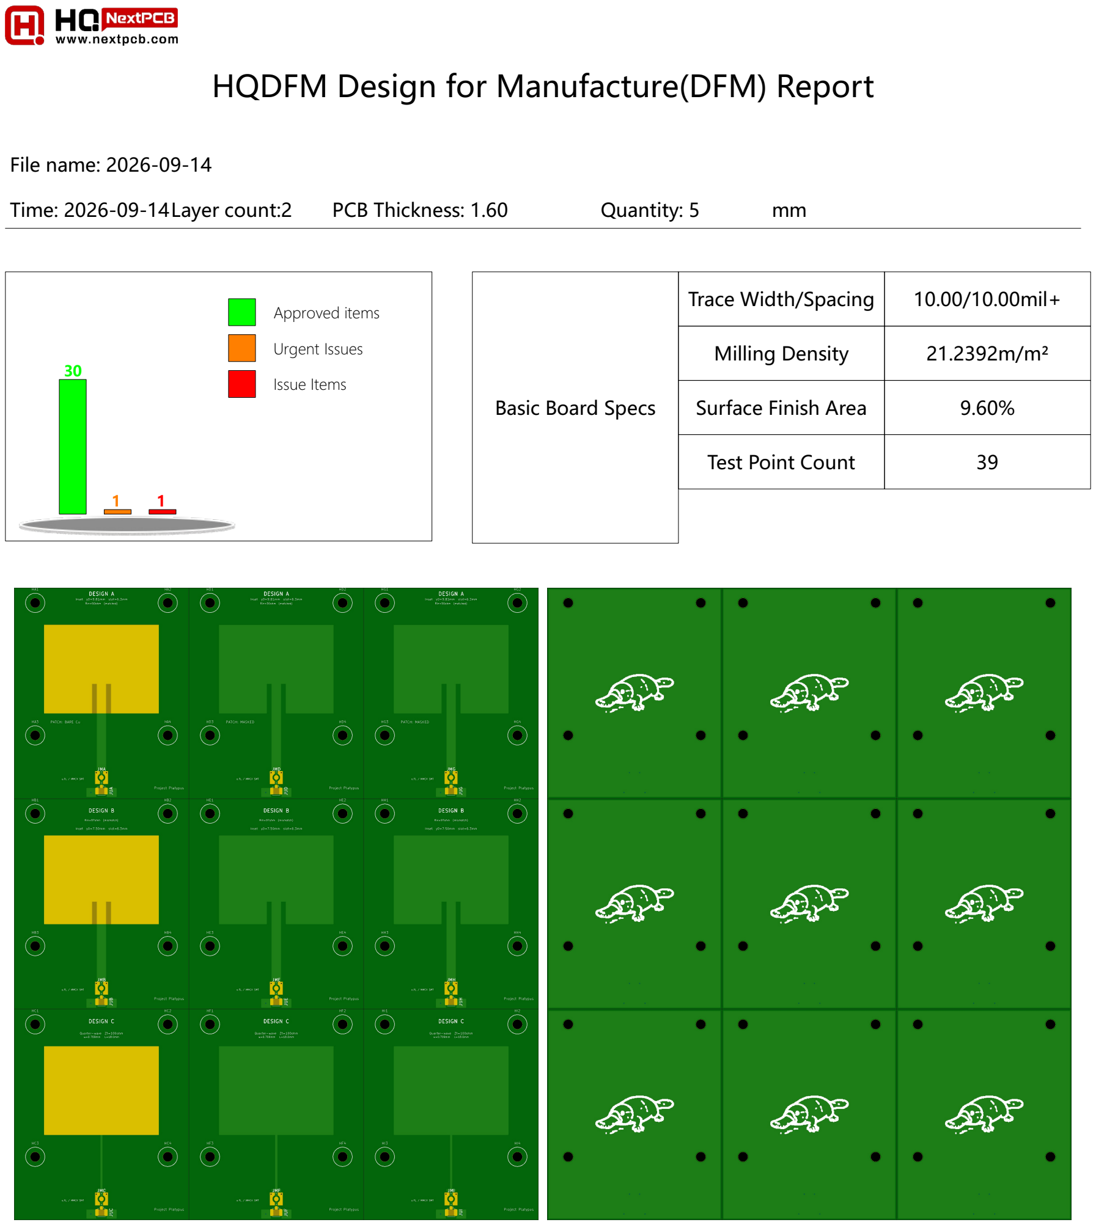
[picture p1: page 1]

Time: 2026-09-14Layer count:2 | PCB Thickness: 1.60 | Quantity: 5
mm

Approved items

Urgent Issues

Issue Items

30

1 1

Basic Board Specs | Trace Width/Spacing | 10.00/10.00mil+
| Milling Density | 21.2392m/m²
| Surface Finish Area | 9.60%
| Test Point Count | 39

Type | Category | No. of Checks | Result
| Open/Shorts (IPC) | 1 | Fail
| Signal Integrity | 4 | Pass
| Smallest Trace Width | 1 | Pass
| Smallest Trace Spacing | 3 | Pass
| SMD Pad Spacing | 1 | Pass
| Pad Size | 3 | Pass
| Hatched Copper Pour | 2 | Pass
| Annular Ring Size | 2 | Pass
| Drill to Copper | 5 | Pass 18 , Fail 36
| Copper-to-Board Edge | 2 | Pass 54
| Holes on SMD Pads | 4 | Pass
PCB Drilling Analysis | Drill Diameter | 8 | Pass 3
| Drill Spacing | 4 | Pass
| Drill to Board Edge | 4 | Pass
| Drill Hole Density | 1 | Pass
| Special Drill Holes | 2 | Pass
| Drill Hole Errors | 3 | Pass
PCB Solder Mask Analysis | Solder Mask Dam | 3 | Pass
| Missing SMask Opening | 1 | Pass
| Solder Paste Area | 1 | Pass
PCB Silk Analysis | Silkscreen Spacing | 1 | Pass

PCB Trace Analysis

PCBA Component Analysis | Component Spacing | 2 | Fail
| Comp Height Analysis | 3 | Pass
| Comp.-to-Board-Edge | 3 | Fail
| Component Silkscreen Spacing | 0 | Fail
| Pad Count Mismatch | 4 | Fail
| Designator Length | 0 | Fail
| Double-sided Components | 1 | Pass
| Mid Mount Comp | 1 | Pass
PCBA Pin Analysis | SMT Pad Analysis | 8 | Fail
| Through-hole Pins | 10 | Fail
PCBA Pad Analysis | Chip Pads | 60 | Fail
PCBA Fiducial Analysis | Fiducial Count | 1 | Fail
| Fiducial Analysis | 4 | Pass

ID | Check | Limits | Value | Issue | Image | Position | Qty | Level

1

### Drill to

Copper_NP
TH-to- Copper

8,10,12

0.25

mm

NPTH to copper spacing of
9.86mil was detected in
your design. This could
increase the risk of defects

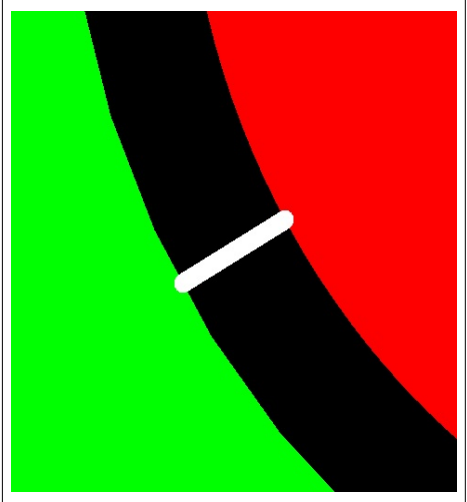
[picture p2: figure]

such as short circuits, which decrease manufacturing
efficiency and yield, and

### affect the reliability of the

boards. It is recommended
to increase the spacing to at least 12 mil.
185.51,-209.86 | 36 | Warnin g

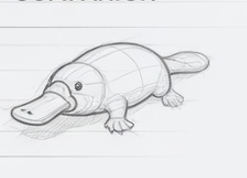
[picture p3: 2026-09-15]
assets/platypus_mascot.png

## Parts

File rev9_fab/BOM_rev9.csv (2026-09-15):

Comment | Designator | Footprint | LCSC Part #
U.FL-R-SMT-1(10) | JUD,JUE,JUF | U.FL_Hirose_U.FL-R-SMT-1_Vertical | C88373
WR-MMCX 66012102111404 | JMA,JMB,JMC,JMG,JMH,JMI | WR-MMCX_Wuerth_66012102111404_Vertical | GLOBAL-SOURCING (Wurth 66012102111404)

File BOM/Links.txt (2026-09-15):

# Vendor datasheets (PDFs deliberately not committed — see PROJECT_STATUS.md)

## Rev 9 connectors
# Wurth WR-MMCX vertical SMT jack 66012102111404 (JMA-JMI) — land pattern on page 1
https://www.we-online.com/components/products/datasheet/66012102111404.pdf
# Hirose U.FL-R-SMT-1 (JUA-JUI) — U.FL series catalog with recommended PCB pattern + metal mask
https://www.hirose.com/en/product/document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
# Hirose U.FL-R-SMT-1 datasheet mirror (LCSC-hosted PDF)
https://datasheet.lcsc.com/lcsc/2006112255_HRS-Hirose-U-FL-R-SMT-1-01_C598199.pdf

## Rev 7.13.1 (manufactured, edge-launch)
# Cinch/Johnson MMCX edge-launch 135-3711-801
https://www.digikey.com/en/products/detail/cinch-connectivity-solutions-johnson/135-3711-801/263441

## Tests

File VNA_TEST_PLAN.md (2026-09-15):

# Project Platypus — VNA Test Plan & Milestones

*Bench characterization of the 2.4 GHz patch antennas. Complements `TEST_PROCEDURE.md`
(over-the-air RSSI testing). Written for two instrument tiers:*

- **Tier 1 — NanoVNA at home.** Buy a **NanoVNA-V2 Plus4 / SAA-2N or LiteVNA-64** —
  these measure 2.4 GHz on the fundamental. The original NanoVNA (900 MHz fundamental,
  harmonic mode above) has poor dynamic range at 2.4 GHz; don't buy that one for this.
- **Tier 2 — the good stuff at work.** Any calibrated lab VNA covering 1–3 GHz, and
  whatever radar test infrastructure exists (signal generator + horn, absorber panels,
  possibly a chamber). Tier 2 runs settle the science; Tier 1 is for fast iteration.

## Fixture & calibration rules (apply to every milestone)

1. **Cal plane = the far end of the pigtail.** Calibrate SOL (open/short/load) at the
   SMA/SMP end with the cal standards, then connect the SMP→MMCX pigtail and either
   (a) accept the pigtail inside the measurement (fine — it's part of the deployed
   system), or (b) on the work VNA, use port extension / de-embed the pigtail's delay
   so the reference plane lands at the MMCX. Record which convention every dataset uses.
2. **Antennas are sensitive to their surroundings.** Measure with ≥30 cm clearance to
   metal/bodies: prop the board on a foam block, patch facing up into clear space,
   hands off during sweep. At work, a panel of absorber under/behind is ideal.
3. **Sweep setup:** 2.0–3.0 GHz, ≥201 points for survey; 2.35–2.55 GHz narrow for
   resonance metrology. 915 MHz work later: 0.85–0.98 GHz.
4. **Data hygiene:** save Touchstone `.s1p` for every sweep. Naming:
   `s11_<rev>_<design><board#>_<bare|mask>_<instrument>_<date>.s1p`, e.g.
   `s11_r7.13_C1_mask_litevna_2026-08-09.s1p`. Keep them in a `measurements/` folder
   (add to the repo only for the released revision). Log temperature and fixture notes.

---

## Milestone 0 — Instrument sanity check

Before trusting anything: cal, then re-measure the load standard (should sit at centre
of Smith chart, |S11| < −30 dB across band), an open pigtail (|S11| ≈ 0 dB, phase
spinning), and repeat one antenna sweep twice with a re-mate in between.

**Gate:** load < −30 dB; two re-mated sweeps of the same antenna agree on f₀ within
±5 MHz and on |S11| depth within 2 dB. If not, fix the fixture before proceeding.

## Milestone 1 — Rev 7.13 A/B/C: does the antenna resonate where the math says?

Sweep all three manufactured boards (masked patches, edge-launch MMCX). Extract per
board: f₀ (minimum |S11|), return loss at f₀, −10 dB bandwidth, and the impedance at
f₀ from the Smith chart.

**Predictions to test:**
| Board | Predicted | Pass band |
|---|---|---|
| A (inset, matched) | f₀ ≈ 2.40 GHz minus mask detune (expect ~2.37–2.39), RL > 15 dB | f₀ within 2.35–2.45 GHz |
| B (inset, mismatch) | same f₀, RL ≈ 7–10 dB | RL clearly worse than A |
| C (λ/4 transformer) | same f₀, RL > 12 dB | f₀ within 2.35–2.45 GHz |

**Gate:** all three resonate in-band. If a board shows *no* resonance dip at all →
connector/feed fault (this is the definitive version of the patch-A question from field
testing — a dead joint shows a near-flat |S11| ≈ 0 dB trace).

## Milestone 2 — The edge-resistance experiment (the real science)

The one soft input in the whole design chain is Rin_edge (assumed 200 Ω; Balanis says
~300–400 Ω). Design B exists to measure it:

1. Read R + jX at f₀ for boards A and B from the Smith chart.
2. Rin_edge = R_measured / cos²(π·y₀/L) with y₀ = 9.81 mm (A) and 7.50 mm (B),
   L = 29.44 mm. Two boards → two independent estimates; they should agree.

**Gate/outcome:** a consistent Rin_edge number. Write it into the design notes — it
recalibrates the inset formula for every future design (including 915 MHz: y₀ scales
directly). This single measurement retires the biggest open assumption in the project.

## Milestone 3 — Mask detune quantification (needs Rev 8/9 boards)

When the Rev 9 panel arrives: identical designs exist bare (column 1) and masked
(columns 2–3). Sweep one bare + one masked copy of the same design, same fixture.

**Deliverable:** Δf₀ in MHz (prediction: mask pulls resonance down 10–30 MHz). This
number decides whether future revisions pre-compensate patch length for masked builds,
and it's a great plot for the Hackster/Tindie story.

## Milestone 4 — Rev 9 connector-land comparison

Same panel: sweep a u.FL-fitted board vs an MMCX-fitted board of the same design, and
compare both against a Rev 7.13 edge-launch board. This measures the 0.6 mm neck +
unpopulated-land stub discontinuity.

**Gate:** RL at f₀ within ~2 dB and f₀ within ~10 MHz across connector variants → the
SMT lands are RF-transparent enough, ship whichever connector the market wants. A big
deviation on one variant → look at that land geometry before productizing it.

## Milestone 5 — Radiation pattern & gain (work facility)

The VNA gives matching, not gain — this milestone needs the radar bench: signal source
+ standard-gain horn (or any characterized 2.4 GHz antenna) at a few metres in the
clearest space available, patch on a rotator or hand-stepped in 15° increments.

1. **Gain by comparison:** received power through the patch vs through a reference
   antenna of known gain, same position/polarization → G_patch = G_ref + ΔP.
   Prediction: 4–6 dBi realized (5–7 dBi directivity minus FR4 loss).
2. **Azimuth + elevation cuts:** normalized pattern, front-to-back ratio.
   Prediction: F/B only ~6–10 dB (small ground plane — this measurement closes out the
   "no difference at 180°" field observation with real numbers).
3. **Polarization check:** rotate the patch 90° about boresight — cross-pol should drop
   >15 dB. Confirms the linear polarization axis for mounting guidance.

**Deliverable:** pattern plots + an absolute realized-gain figure (dBi) for the product
page — the characterisation the project does not yet have.

## Milestone 6 — (later) 915 MHz bracket-panel selection

When the Meshtastic bracket panel exists: sweep variants A/B/C (L = 77.09/78.67/
80.24 mm), pick whichever lands closest to 906.875 MHz, and back out the batch's true
εr from the winner. Five-minute job with the NanoVNA that replaces a whole field-test
campaign — this is the milestone that justifies the instrument purchase by itself.

---

## Decision map (what each milestone unblocks)

| Milestone | Decision it feeds |
|---|---|
| M1 | Is patch A's connector joint dead? (reflow or exonerate) |
| M2 | Corrected Rin_edge → 915 MHz inset depth, all future insets |
| M3 | Pre-compensate L for masked builds? Bare-patch SKU story |
| M4 | Ship u.FL, MMCX, or both — with data |
| M5 | Absolute gain + patterns for product listing & Hackster |
| M6 | 915 production geometry + batch εr |

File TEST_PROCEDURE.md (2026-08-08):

# Antenna Test Procedure
## 2.4 GHz Patch Antenna — M5Tab5 Integration
### Rev 1.0

---

## Overview

This document covers the complete test workflow for characterising the patch antenna PCB against the M5Tab5 stock chip antenna, culminating in a live 3D radiation pattern rendered on the M5Tab5 display using the BMI270 gyroscope for real-time orientation.

**Three designs under test:**
- Design A — inset feed, y₀ = 9.5 mm (baseline calculated)
- Design B — inset feed, y₀ = 7.5 mm (tighter match, wider notch)
- Design C — λ/4 transformer, Z_t ≈ 100 Ω, no notch

---

## Equipment List

| Item | Purpose | Notes |
|---|---|---|
| M5Tab5 | DUT and renderer | Stock chip antenna for baseline |
| MMCX pigtail, RG178, ~100mm | Connect PCB to M5Tab5 | SMP male to MMCX male |
| WiFi access point | Signal source | Fixed position, fixed channel, fixed power |
| Rotating platform | Pattern sweep | Lazy susan or tripod head, marked in 15° increments |
| Measuring tape | Distance calibration | Mark floor at 1, 2, 3, 4, 5 m from AP |
| Non-metallic surface | Reduce reflections | Wooden table or cardboard |
| USB-C power | Power M5Tab5 during test | Keeps battery level consistent |
| Laptop with serial monitor | Log RSSI data | Arduino Serial Plotter or minicom |
| SD card (FAT32) | On-device logging | 512 MB minimum |
| Python 3 environment | Data processing | numpy, scipy, json |
| Masking tape | Mark floor grid | Label angular positions |

**Optional (strongly recommended for Rev 3):**
- NanoVNA or similar VNA → measure S11 directly on each PCB before RF testing
- Calibration resistor set → verify VNA port impedance

---

## Phase 0 — Environment Setup

### 0.1 Access point configuration
- Lock AP to 2.4 GHz band only (disable 5 GHz if possible)
- Lock to channel 6 (centre of 2.4 GHz band, avoids edge effects)
- Disable beamforming / adaptive antenna features (these change power dynamically)
- Set transmit power to maximum and lock it there
- Note: AP should be elevated 1.2–1.5 m above floor (approximate head height)

### 0.2 Room preparation
- Remove large metal objects from the test area (chairs with metal legs, filing cabinets)
- Mark the floor with masking tape: a cross centred under the AP, arms extending 5 m in 4 cardinal directions
- Mark 15° increments around the rotation centre point (3 m from AP)
- Run a quick sanity check: walk the test path with the M5Tab5 running RSSI logger, confirm RSSI decreases monotonically with distance and is stable (< 2 dBm variation over 5 s at fixed position)

### 0.3 M5Tab5 firmware

Flash the following logging sketch before starting. The sketch logs RSSI continuously at 1 Hz to both Serial and SD card.

```cpp
#include <WiFi.h>
#include <SD.h>
#include <SPI.h>

const char* SSID     = "YOUR_AP_SSID";
const char* PASSWORD = "YOUR_AP_PASS";
const char* LOG_FILE = "/rssi_log.csv";

File logFile;

void setup() {
  Serial.begin(115200);
  WiFi.begin(SSID, PASSWORD);
  while (WiFi.status() != WL_CONNECTED) delay(500);

  SD.begin(/* your SD CS pin */);
  logFile = SD.open(LOG_FILE, FILE_APPEND);
  logFile.println("timestamp_ms,design_id,theta_deg,phi_deg,rssi_dbm,note");
  logFile.flush();
  Serial.println("timestamp_ms,design_id,theta_deg,phi_deg,rssi_dbm,note");
}

void loop() {
  wifi_ap_record_t ap;
  esp_wifi_sta_get_ap_info(&ap);
  int8_t rssi = ap.rssi;

  String row = String(millis()) + ",?,0,0," + String(rssi) + ",";
  logFile.println(row);
  logFile.flush();
  Serial.println(row);
  delay(1000);
}
```

**During testing:** edit `design_id`, `theta_deg`, `phi_deg` fields manually or via Serial command before each measurement position. The `note` field is free text for marking events.

---

## Phase 1 — Baseline (Stock Chip Antenna)

**Goal:** Establish ground truth RSSI performance before any external antenna is connected. Every result in Phases 2–3 is expressed as ΔG = RSSI_measured − RSSI_baseline at the same position.

### 1.1 Static range test

1. Place M5Tab5 flat on non-metallic surface, screen facing up, USB-C at the back
2. Fix orientation — do not rotate between measurements
3. Start RSSI logger, set design_id = "BASELINE", note = "static_range"
4. Walk to each distance mark (1, 2, 3, 4, 5 m) in the direction facing the AP
5. At each mark: stand still 5 s, record 10 RSSI readings, take median
6. Repeat in all 4 cardinal directions (16 data points total per orientation)

**Record in spreadsheet:**

| Distance (m) | Direction | RSSI median (dBm) | Std dev |
|---|---|---|---|
| 1 | N | | |
| 2 | N | | |
| ... | | | |

### 1.2 Azimuth pattern (2D sweep)

1. Place M5Tab5 on rotating platform at 3 m from AP, screen facing up (patch horizontal)
2. Align 0° to face directly at AP
3. Set note = "baseline_azimuth"
4. Rotate through 0°, 15°, 30° … 345° (24 positions)
5. At each position: pause 3 s, collect 5 RSSI samples, record median
6. Export as CSV: `baseline_azimuth.csv`

### 1.3 Key metrics to record

| Metric | Formula | Value |
|---|---|---|
| Peak RSSI | max(RSSI) | |
| Null RSSI | min(RSSI) | |
| Peak-to-null ratio | peak − null (dBm) | |
| RSSI at 3 m broadside | direct reading | |
| Distance at −70 dBm | interpolate from range test | |

---

## Phase 2 — Per-Design Static Comparison

**Goal:** Quickly rank Designs A, B, C before committing to the full 3D sweep. Run the same tests as Phase 1 with each design connected.

### 2.1 Connecting the external antenna

1. Plug MMCX pigtail into M5Tab5 MMCX port (the one labelled for external antenna)
2. In firmware or hardware, switch M5Tab5 to external antenna mode (RF switch — check Tab5 schematic; GPIO controls the antenna switch on ESP32-C6-MINI-1U)
3. Connect SMP end of pigtail to J1 on the design under test
4. Mount design PCB patch-face-up, in the same orientation as the baseline M5Tab5 position

### 2.2 RF switch note

The M5Tab5 ESP32-C6-MINI-1U has an integrated RF switch between the on-chip antenna and the MMCX port. You must assert the correct GPIO to route RF to the external port. Check the Tab5 schematic for the exact GPIO number — it is likely driven by a SKY13351 or similar SPDT. Without switching, both the chip antenna and external antenna may be active simultaneously, corrupting results.

```cpp
// Example — verify GPIO number from Tab5 schematic
#define ANT_SEL_GPIO 14  // CONFIRM THIS FROM SCHEMATIC
pinMode(ANT_SEL_GPIO, OUTPUT);
digitalWrite(ANT_SEL_GPIO, HIGH);  // HIGH = external MMCX
```

### 2.3 Repeat static tests

For each design (A, B, C):
- Repeat 1.1 (static range test) with design_id = "A", "B", or "C"
- Repeat 1.2 (azimuth sweep) with same design_id
- Calculate ΔG at each position vs baseline

### 2.4 Comparison table

| Position | Baseline (dBm) | Design A (dBm) | ΔG_A | Design B (dBm) | ΔG_B | Design C (dBm) | ΔG_C |
|---|---|---|---|---|---|---|---|
| 3 m broadside | | | | | | | |
| 3 m 90° | | | | | | | |
| 3 m 180° | | | | | | | |
| 5 m broadside | | | | | | | |

**Decision gate:**
- ΔG > +4 dBm broadside → design is working, proceed to Phase 3
- ΔG 2–4 dBm → marginal, file/trim the notch or transformer section, re-test
- ΔG < +2 dBm → probable impedance mismatch, check connector seating, then use VNA

---

## Phase 3 — Full 3D Radiation Pattern

**Goal:** Collect (θ, φ, RSSI) over a full hemisphere for the winning design. This data feeds the M5Tab5 renderer.

### 3.1 Angular grid

- φ (azimuth): 0° to 345° in 15° steps = 24 positions
- θ (elevation): 0° (horizontal) to 90° (vertical, patch facing up) in 15° steps = 7 elevation planes
- Total positions: 24 × 7 = **168 measurements**
- Estimated time: ~50 minutes at 3 s per position

### 3.2 Jig setup

The antenna PCB must be rotatable in both azimuth and elevation. A practical approach:
1. Azimuth: rotating platform as used in Phase 2
2. Elevation: tilt the entire platform by propping up one edge at 15° increments (a stack of books works)
3. Mark each elevation angle with a bubble level or phone inclinometer app

### 3.3 Data collection procedure

For each elevation plane θ:
1. Set jig to elevation θ
2. Rotate through all 24 azimuth positions
3. At each (θ, φ): pause 2 s, collect 10 RSSI samples, record median and std deviation
4. If std > 3 dBm at any position: wait 5 s, retake. Discard outliers (multipath spike).

**CSV format:**
```
theta_deg,phi_deg,rssi_median_dbm,rssi_std,n_samples,design_id
0,0,-48.2,1.1,10,A
0,15,-49.0,0.8,10,A
0,30,-52.1,1.4,10,A
...
```

### 3.4 Data validation checks

After collection, run these sanity checks before processing:

```python
import pandas as pd
import numpy as np

df = pd.read_csv('pattern_3d.csv')

# Check coverage
assert len(df) == 168, f"Missing positions: {168 - len(df)}"

# Check for outliers
suspect = df[df['rssi_std'] > 3.0]
if len(suspect) > 0:
    print(f"High variance positions ({len(suspect)}):")
    print(suspect[['theta_deg','phi_deg','rssi_std']])

# Check range is physically plausible
assert df['rssi_median_dbm'].between(-90, -20).all(), "RSSI out of range"

print("Range:", df['rssi_median_dbm'].min(), "to", df['rssi_median_dbm'].max(), "dBm")
print("Spread:", df['rssi_median_dbm'].max() - df['rssi_median_dbm'].min(), "dB")
```

Expected spread for a patch antenna: 8–15 dB between broadside peak and worst null.

---

## Phase 4 — M5Tab5 3D Visualization Pipeline

### 4.1 Python: CSV to Three.js JSON

```python
import pandas as pd
import numpy as np
import json

df = pd.read_csv('pattern_3d.csv')

# Normalise RSSI to 0–1 radius
rssi = df['rssi_median_dbm'].values
r_norm = (rssi - rssi.min()) / (rssi.max() - rssi.min())

vertices = []
colors = []

for i, row in df.iterrows():
    theta = np.radians(row['theta_deg'])
    phi   = np.radians(row['phi_deg'])
    r     = r_norm[i]

    x = r * np.sin(theta) * np.cos(phi)
    y = r * np.cos(theta)
    z = r * np.sin(theta) * np.sin(phi)
    vertices.append([round(x, 4), round(y, 4), round(z, 4)])

    # Colour map: teal (high) to gray (low)
    t = r_norm[i]
    colors.append([
        round(0.11 + (1 - t) * 0.4, 3),   # R
        round(0.62 + (1 - t) * 0.0, 3),   # G
        round(0.46 + (1 - t) * 0.1, 3),   # B
    ])

output = {
    "vertices": vertices,
    "colors": colors,
    "rssi_min": float(rssi.min()),
    "rssi_max": float(rssi.max()),
    "design": "A",
    "freq_ghz": 2.4
}

with open('pattern.json', 'w') as f:
    json.dump(output, f)

print(f"Exported {len(vertices)} vertices")
```

### 4.2 Three.js renderer on M5Tab5

The M5Tab5 runs a lightweight web server (ESP-IDF + HTTPS server or Arduino AsyncWebServer). The renderer is an HTML page served from SPIFFS or SD card, loaded in the M5Tab5 browser or a custom LVGL WebView.

```javascript
// Core Three.js pattern renderer
import * as THREE from 'three';

const scene = new THREE.Scene();
const camera = new THREE.PerspectiveCamera(60, w/h, 0.01, 10);
camera.position.set(0, 0, 2.5);

// Load pattern data
const data = await fetch('/pattern.json').then(r => r.json());

const geo = new THREE.BufferGeometry();
const positions = new Float32Array(data.vertices.flat());
const colors    = new Float32Array(data.colors.flat());
geo.setAttribute('position', new THREE.BufferAttribute(positions, 3));
geo.setAttribute('color',    new THREE.BufferAttribute(colors, 3));

const mat = new THREE.PointsMaterial({
  size: 0.05,
  vertexColors: true,
  sizeAttenuation: true
});
scene.add(new THREE.Points(geo, mat));

// BMI270 gyro → quaternion → Three.js camera rotation
// Read quaternion from BMI270 via I2C, apply to scene rotation
function applyGyro(qw, qx, qy, qz) {
  scene.quaternion.set(qx, qy, qz, qw);
}
```

### 4.3 BMI270 orientation feed

The BMI270 on M5Tab5 outputs raw accelerometer + gyroscope data. Use a complementary filter or Mahony filter to produce a quaternion, then feed it to Three.js.

```cpp
// Simplified complementary filter for orientation
// dt = loop time in seconds, typically 0.02 (50 Hz)
float pitch = alpha * (pitch + gyr_x * dt) + (1 - alpha) * atan2(acc_y, acc_z);
float roll  = alpha * (roll  + gyr_y * dt) + (1 - alpha) * atan2(acc_x, acc_z);
// Send pitch, roll, yaw to renderer via WebSocket
ws.send("{\"p\":" + String(pitch) + ",\"r\":" + String(roll) + "}");
```

---

## Phase 5 — Iteration Decision Gate

### 5.1 Results interpretation

| Outcome | Meaning | Action |
|---|---|---|
| ΔG > +5 dBm broadside, pattern shows clear lobe | Design working well | Proceed to Rev 3 production run |
| ΔG +2–5 dBm, pattern visible | Partial match, some loss | File/trim to adjust y₀ or λ/4 length, re-test |
| ΔG < +2 dBm, pattern near-omnidirectional | Impedance mismatch dominant | VNA S11 measurement required |
| ΔG negative (worse than stock) | Connector or RF switch issue | Check pigtail, antenna switch GPIO |

### 5.2 Physical tuning without PCB respin

**Inset feed (Designs A, B):**
- Notch too shallow (Rin > 50 Ω): carefully file 0.3 mm deeper into the notch slot with a needle file. Re-test after each pass.
- Notch too deep (Rin < 50 Ω): add a thin strip of copper tape (~0.3 mm) to the notch wall to reduce effective depth.
- Patch resonance shifted: file the radiating edge to shift frequency up, or add copper tape strip to shift down.

**Quarter-wave transformer (Design C):**
- Section too long (match frequency too low): score and trim 1–2 mm from the far end of the transformer section with a razor knife.
- Section too short (match frequency too high): not field-fixable. Note the delta and correct in Rev 3.

### 5.3 Rev 3 changes to implement based on results

Record the winning y₀ or transformer length, and any frequency offset, here:

| Parameter | Calculated | Measured optimal | Delta |
|---|---|---|---|
| Inset depth y₀ | 9.5 mm | | |
| Patch length L | 28.8 mm | | |
| Transformer length | calculated | | |
| Resonant frequency | 2.40 GHz | | |

---

## Data Files Checklist

By the end of testing, you should have:

- [ ] `baseline_range.csv` — Phase 1 static range
- [ ] `baseline_azimuth.csv` — Phase 1 azimuth sweep
- [ ] `design_A_range.csv` — Phase 2
- [ ] `design_A_azimuth.csv` — Phase 2
- [ ] `design_B_range.csv` — Phase 2
- [ ] `design_B_azimuth.csv` — Phase 2
- [ ] `design_C_range.csv` — Phase 2
- [ ] `design_C_azimuth.csv` — Phase 2
- [ ] `pattern_3d.csv` — Phase 3 full hemisphere (winning design)
- [ ] `pattern.json` — Phase 4 processed for Three.js
- [ ] Photos of each design mounted on test jig
- [ ] VNA S11 screenshots (if available)

---

## Notes & Known Limitations

- RSSI-based measurements are affected by multipath, furniture, and human body proximity. Stand at least 1 m behind the M5Tab5 during measurements and always in the same relative position.
- The M5Tab5's WiFi RSSI resolution is 1 dBm. Differences < 2 dBm are within measurement noise and should not be interpreted as real gain changes.
- This procedure characterises receive sensitivity pattern, not transmit pattern. For a passive reciprocal antenna (which this is), transmit and receive patterns are identical by the reciprocity theorem — so receive RSSI measurements directly characterise the antenna's gain pattern in both directions.
- Indoor multipath will smear the pattern compared to a true anechoic result. The null depth will appear shallower than the true free-space pattern. This is acceptable for comparative testing — the key metrics are ΔG and relative pattern shape, not absolute dBi values.

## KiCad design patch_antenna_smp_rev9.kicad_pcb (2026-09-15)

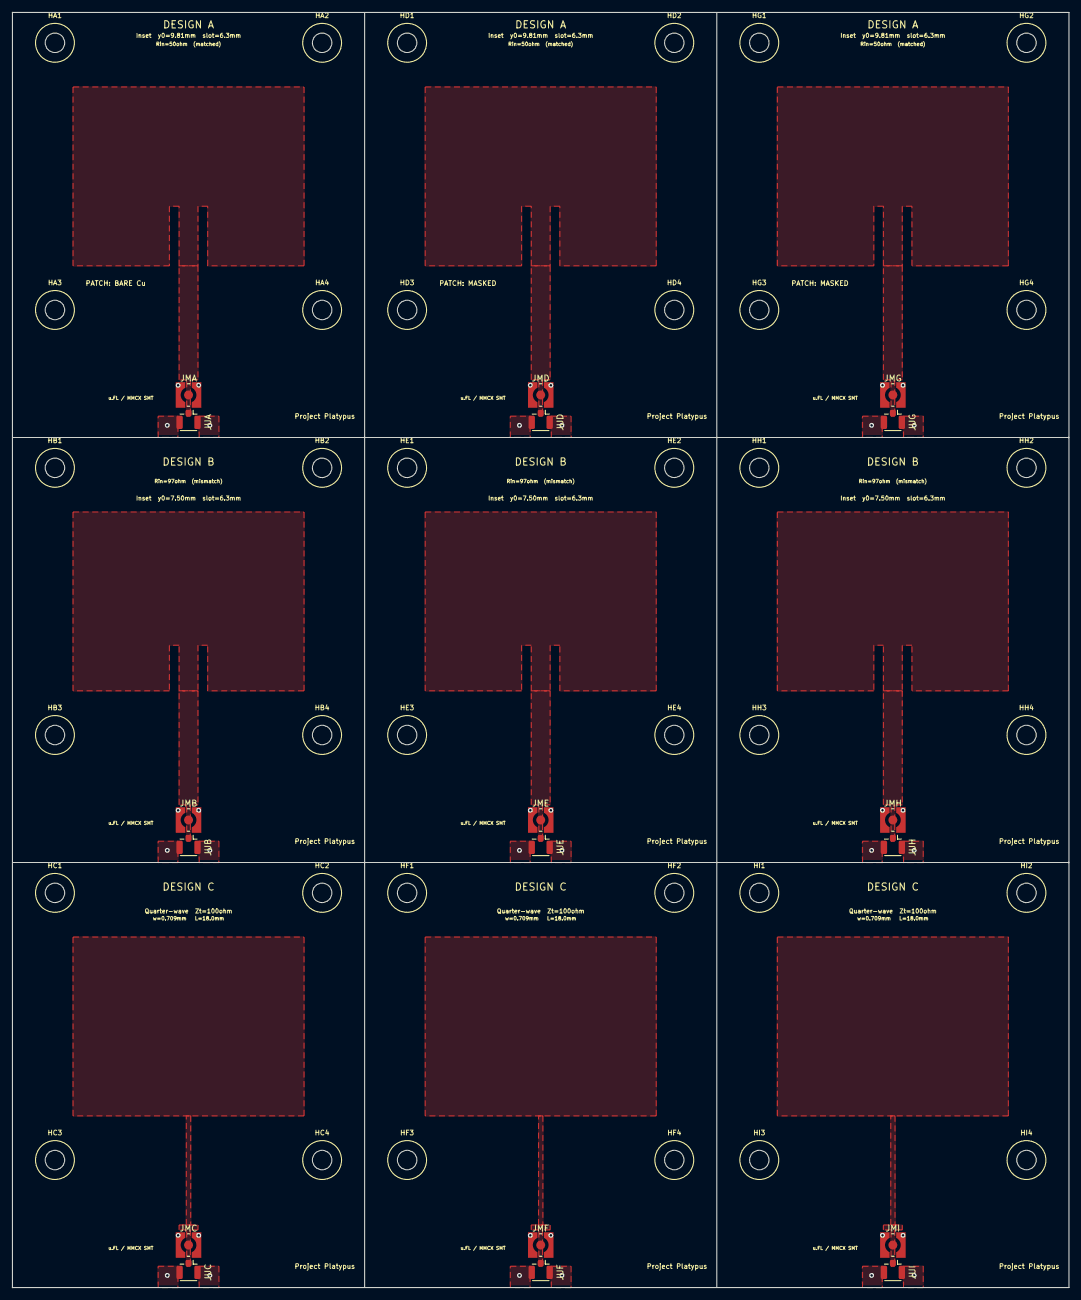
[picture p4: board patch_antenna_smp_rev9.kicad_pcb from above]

Board: 2 copper layers, 174.0 x 210.0 mm, 54 parts (0 on the bottom side), 2 nets, no tracks yet.

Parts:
HA1, HA2, HA3, HA4: M3; M3_NPTPH
HB1, HB2, HB3, HB4: M3; M3_NPTPH
HC1, HC2, HC3, HC4: M3; M3_NPTPH
HD1, HD2, HD3, HD4: M3; M3_NPTPH
HE1, HE2, HE3, HE4: M3; M3_NPTPH
HF1, HF2, HF3, HF4: M3; M3_NPTPH
HG1, HG2, HG3, HG4: M3; M3_NPTPH
HH1, HH2, HH3, HH4: M3; M3_NPTPH
HI1, HI2, HI3, HI4: M3; M3_NPTPH
JMA: WR-MMCX 66012102111404; WR-MMCX_Wuerth_66012102111404_Vertical
JMB: WR-MMCX 66012102111404; WR-MMCX_Wuerth_66012102111404_Vertical
JMC: WR-MMCX 66012102111404; WR-MMCX_Wuerth_66012102111404_Vertical
JMD: WR-MMCX 66012102111404; WR-MMCX_Wuerth_66012102111404_Vertical
JME: WR-MMCX 66012102111404; WR-MMCX_Wuerth_66012102111404_Vertical
JMF: WR-MMCX 66012102111404; WR-MMCX_Wuerth_66012102111404_Vertical
JMG: WR-MMCX 66012102111404; WR-MMCX_Wuerth_66012102111404_Vertical
JMH: WR-MMCX 66012102111404; WR-MMCX_Wuerth_66012102111404_Vertical
JMI: WR-MMCX 66012102111404; WR-MMCX_Wuerth_66012102111404_Vertical
JUA: U.FL-R-SMT-1; U.FL_Hirose_U.FL-R-SMT-1_Vertical
JUB: U.FL-R-SMT-1; U.FL_Hirose_U.FL-R-SMT-1_Vertical
JUC: U.FL-R-SMT-1; U.FL_Hirose_U.FL-R-SMT-1_Vertical
JUD: U.FL-R-SMT-1; U.FL_Hirose_U.FL-R-SMT-1_Vertical
JUE: U.FL-R-SMT-1; U.FL_Hirose_U.FL-R-SMT-1_Vertical
JUF: U.FL-R-SMT-1; U.FL_Hirose_U.FL-R-SMT-1_Vertical
JUG: U.FL-R-SMT-1; U.FL_Hirose_U.FL-R-SMT-1_Vertical
JUH: U.FL-R-SMT-1; U.FL_Hirose_U.FL-R-SMT-1_Vertical
JUI: U.FL-R-SMT-1; U.FL_Hirose_U.FL-R-SMT-1_Vertical

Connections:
GND: JMA.2, JMB.2, JMC.2, JMD.2, JME.2, JMF.2, JMG.2, JMH.2, JMI.2, JUA.2, JUB.2, JUC.2, JUD.2, JUE.2, JUF.2, JUG.2, JUH.2, JUI.2
RF_IN: JMA.1, JMB.1, JMC.1, JMD.1, JME.1, JMF.1, JMG.1, JMH.1, JMI.1, JUA.1, JUB.1, JUC.1, JUD.1, JUE.1, JUF.1, JUG.1, JUH.1, JUI.1

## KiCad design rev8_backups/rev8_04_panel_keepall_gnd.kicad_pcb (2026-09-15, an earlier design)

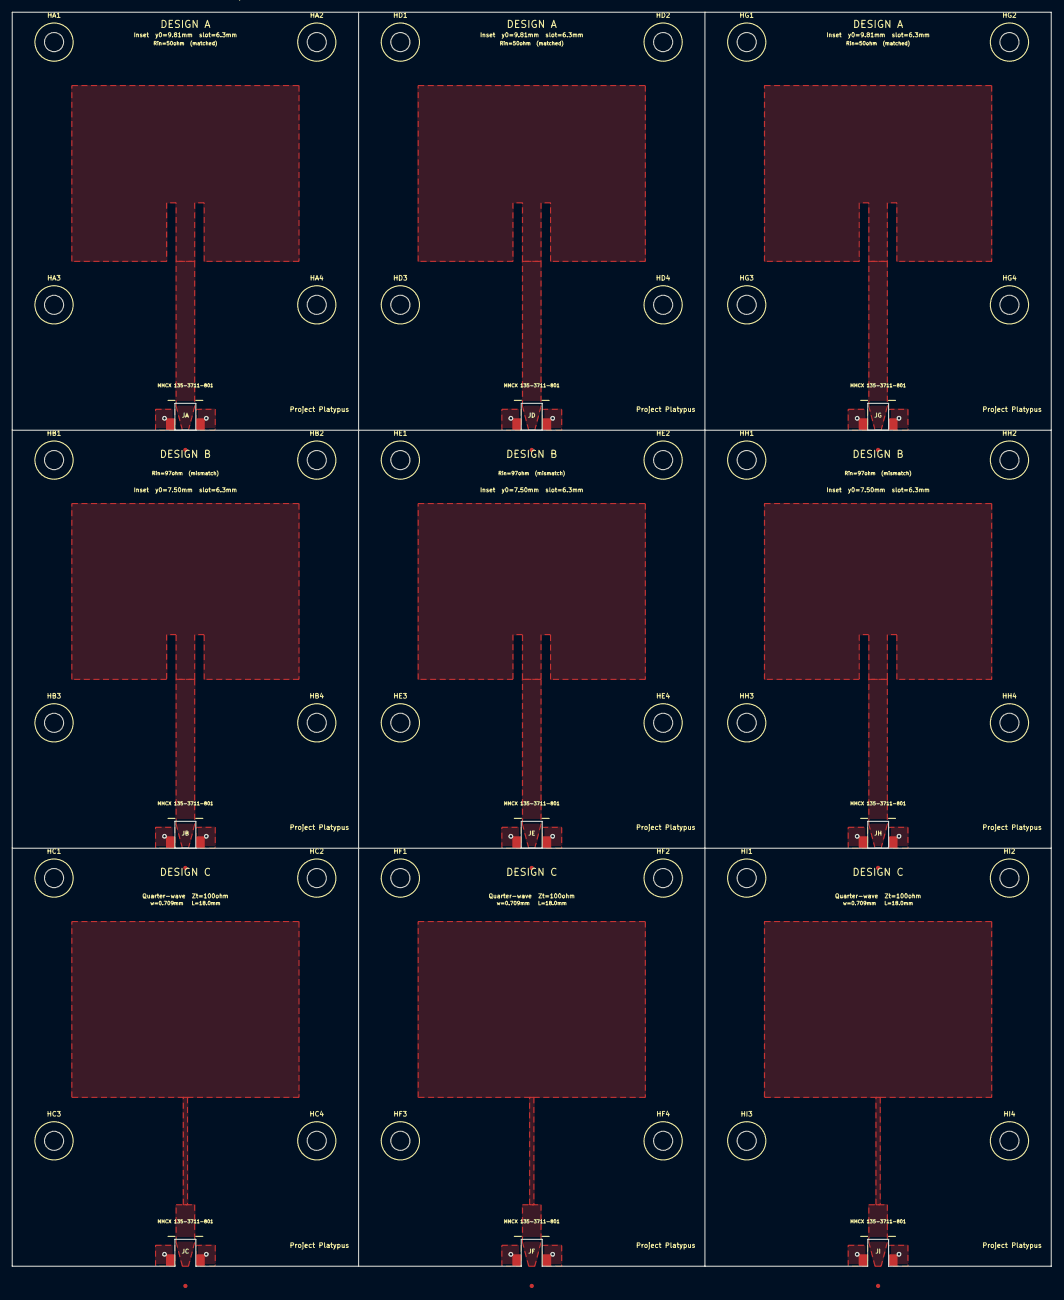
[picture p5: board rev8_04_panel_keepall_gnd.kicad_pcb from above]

Board: 2 copper layers, 174.0 x 210.0 mm, 45 parts (0 on the bottom side), 2 nets, no tracks yet.

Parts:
HA1, HA2, HA3, HA4: M3; M3_NPTPH
HB1, HB2, HB3, HB4: M3; M3_NPTPH
HC1, HC2, HC3, HC4: M3; M3_NPTPH
HD1, HD2, HD3, HD4: M3; M3_NPTPH
HE1, HE2, HE3, HE4: M3; M3_NPTPH
HF1, HF2, HF3, HF4: M3; M3_NPTPH
HG1, HG2, HG3, HG4: M3; M3_NPTPH
HH1, HH2, HH3, HH4: M3; M3_NPTPH
HI1, HI2, HI3, HI4: M3; M3_NPTPH
JA: MMCX-135-3711-801; MMCX_135-3711-801
JB: MMCX-135-3711-801; MMCX_135-3711-801
JC: MMCX-135-3711-801; MMCX_135-3711-801
JD: MMCX-135-3711-801; MMCX_135-3711-801
JE: MMCX-135-3711-801; MMCX_135-3711-801
JF: MMCX-135-3711-801; MMCX_135-3711-801
JG: MMCX-135-3711-801; MMCX_135-3711-801
JH: MMCX-135-3711-801; MMCX_135-3711-801
JI: MMCX-135-3711-801; MMCX_135-3711-801

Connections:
GND: JA.2, JA.3, JB.2, JB.3, JC.2, JC.3, JD.2, JD.3, JE.2, JE.3, JF.2, JF.3, JG.2, JG.3, JH.2, JH.3, JI.2, JI.3
RF_IN: JA.1, JB.1, JC.1, JD.1, JE.1, JF.1, JG.1, JH.1, JI.1

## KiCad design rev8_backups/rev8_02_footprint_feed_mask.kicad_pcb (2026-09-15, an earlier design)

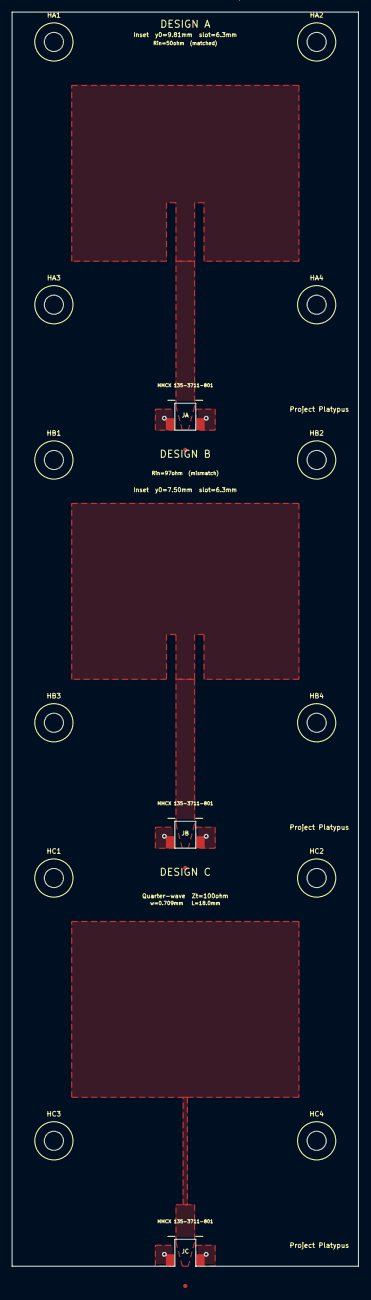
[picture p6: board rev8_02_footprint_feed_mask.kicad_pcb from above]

Board: 2 copper layers, 58.0 x 210.0 mm, 15 parts (0 on the bottom side), 2 nets, no tracks yet.

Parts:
HA1, HA2, HA3, HA4: M3; M3_NPTPH
HB1, HB2, HB3, HB4: M3; M3_NPTPH
HC1, HC2, HC3, HC4: M3; M3_NPTPH
JA: MMCX-135-3711-801; MMCX_135-3711-801
JB: MMCX-135-3711-801; MMCX_135-3711-801
JC: MMCX-135-3711-801; MMCX_135-3711-801

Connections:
GND: JA.2, JA.3, JB.2, JB.3, JC.2, JC.3
RF_IN: JA.1, JB.1, JC.1

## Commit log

2026-08-08 Project Platypus — 2.4 GHz first-principles patch antenna (manufactured Rev 7.13.1)
    Three-design comparison panel (inset-fed matched / inset-fed mismatch control /
    quarter-wave transformer) on FR4 1.6mm, edge-launch MMCX, KiCad. Field-tested:
    +12.5 dB vs host chip antenna. Includes design derivation, test procedure, DRC
    rules, and the as-manufactured JLCPCB gerber package. CERN-OHL-S v2.
    [patch_antenna_smp-B_Cu.gbl, patch_antenna_smp-B_Cu.gbr, patch_antenna_smp-B_Mask.gbr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]
2026-08-13 Withdraw the gain claim pending repeatability
    An early measurement produced an anomalously high delta and was excluded from
    conclusions pending repeatability. It was a single informal test that compared
    an average against a best case, and later desk tests read lower than the chip
    antenna with the patch pointed away from the AP.
    Removed as an assertion from the README, REV8_PLAN and VNA_TEST_PLAN; the repo
    description too. Characterisation is in progress under a controlled procedure.
2026-09-15 Release full project: Rev 8 & Rev 9 designs, 915 MHz study, fab packages, status guide
    Open up the repo from the manufactured-Rev-7.13.1-only scope to the whole project,
    now that the product track is funded: Rev 8 (3x3 panel respin) and Rev 9 (dual SMT
    u.FL + vertical MMCX lands) boards with their design snapshots, the JLCPCB fab and
    assembly package for Rev 9, the 915 MHz Meshtastic design study, the VNA test plan,
    and PROJECT_STATUS.md as the single-file status + machine-transfer guide.
    [BOM_rev9.csv, patch_antenna_smp_rev8.kicad_pcb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]
2026-09-15 Rev 9 pre-order pass: back-silk mascot, silk fix, fab package regen
    - Add platypus mascot (assets/platypus_mascot.png) to B.SilkS on all 9
    boards: 26x12.7mm, mirrored for back view, 375 filled rects per board
    traced from the sketch; clear of mounting holes, vias, and connector
    region. DRC delta unchanged vs documented baseline (9 courtyard +
    7 V-cut outline + 16 panel-artifact unconnected, 0 real defects).
    - Fix stale panel silk note: drop "PURPLE / ENIG" suffix from V-SCORE
    text (ordering green / lead-free HASL).
    - Regenerate full rev9_fab gerber/drill package and
    rev9_gerbers_jlcpcb.zip (kicad-cli 10.0.6, stored board plot params;
    untouched aux layers verified byte-identical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
    [patch_antenna_smp_rev9-B_Courtyard.gbr, patch_antenna_smp_rev9-B_Cu.gbl, patch_antenna_smp_rev9-B_Fabrication.gbr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]
